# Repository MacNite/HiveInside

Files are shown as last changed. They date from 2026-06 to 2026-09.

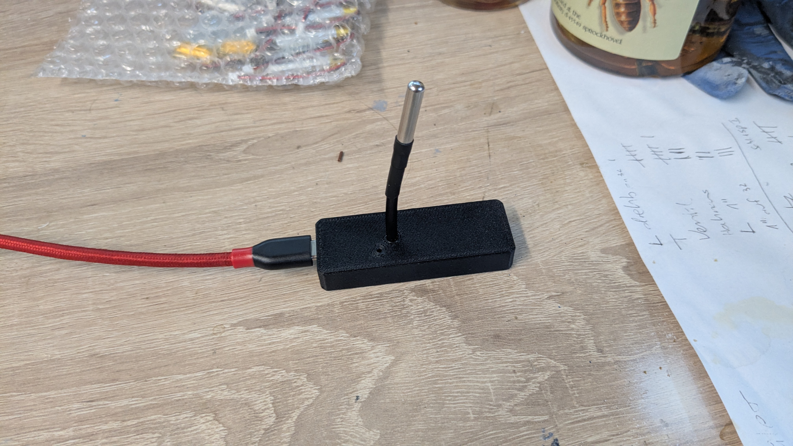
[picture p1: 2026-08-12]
enclosure/enclosure.jpg

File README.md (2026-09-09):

# HiveInside

A stand-alone, battery-powered **in-hive environmental and acoustic sensor** for
beehive monitoring. It broadcasts its readings over **BLE as a beacon** that the
[HiveScale](https://github.com/MacNite/HiveScale) / HiveHub ecosystem picks up
with a passive scan each cycle and bridges to the backend.

- **Target:** Seeed **XIAO nRF54LM20A Sense** with an external SHT40, for low power and a
  compact integrated sensor platform — its on-board 6-axis IMU (LSM6DS3TR-C),
  PDM mic (MSM261DGT006) and nPM1300 PMIC fold most of the discrete sensors onto
  the module. The firmware is a Zephyr application in
  [`firmware-nrf54lm20a/`](firmware-nrf54lm20a), built with west and sysbuild.
  [[buy]](https://www.seeedstudio.com/Seeed-Studio-XIAO-nRF54LM20A-Sense-p-6840.html)

> Part of the open beehive-monitoring ecosystem alongside **HiveScale** (weight /
> external sensing) and **BeeCounter** (entrance traffic).

📖 **[HiveInside website](https://macnite.github.io/HiveInside/website/)** — the
feature set, hardware and BLE payload on one page (source in
[`website/`](website)). The ecosystem hub is the
[HiveHub site](https://macnite.github.io/HiveHub/website/).

---

## Why a separate device?

The frame-mounted accelerometer is, per the literature (Ramsey et al. 2020,
*Sci. Rep.*), the only reliable way to **predict swarming** up to ~30 days ahead —
microphones cannot capture the critical ~20 Hz vibrational signature. HiveInside
puts that accelerometer, plus acoustic FFT bands and climate sensing, **inside**
the hive on a tiny wireless board, avoiding the cabling a wired sensor needs.

---

## Sensors

| Function | Part (XIAO nRF54LM20A Sense) | Interface |
|---|---|---|
| 3-axis vibration (swarm prediction, ~20 Hz) | LSM6DS3TR-C (on-board 6-axis IMU) | I²C |
| Acoustic FFT (piping, hum, stress) | MSM261DGT006 (on-board PDM mic) | PDM |
| Temperature + humidity | SHT40 (external) | I²C |
| Battery voltage + charge | nPM1300 PMIC fuel gauge (on-board) | — |

The firmware also auto-detects an external LIS3DH/LIS2DH12 at `0x18`/`0x19`, so a
breakout-based bench setup runs the same pipeline as the on-board IMU.

Vibration and acoustics are analysed into the same FFT bands as HiveScale, so a
value means the same thing across the ecosystem.

---

## Key features

- **BLE beacon transport** — the full measurement (climate, vibration +
  acoustic FFT bands, battery) broadcasts continuously as a 29-byte
  manufacturer-data advertisement that HiveHub decodes with a passive scan.
  Reading the data needs no connection, pairing window, or wake-sync schedule.
- **Per-node identity** — each node advertises as `HiveInside-XXXX`, where the
  four hex digits are the last two bytes of its BLE address. Several nodes in
  one yard are therefore distinguishable in a scanner and in HiveHub's dashboard
  without any provisioning step; the suffix is derived from the address, so it
  survives a factory erase and a firmware update.
- **Ultra-low power** — the nRF54 idles with only the ~1 s advertiser
  running (a few µA); no deep-sleep rendezvous machinery required. The sensor
  rail (IMU + microphone) is switched off between the five-minute measurements.
- **Authenticated on-request audio** (0.6.0+) — HiveHub can ask the node to
  record from inside the hive; it streams raw 16 kHz PCM16 over BLE with a
  60-second privacy cap, an HMAC-authenticated START and an end-to-end CRC. The
  microphone stays off until an authenticated request owns the link, and a
  session can never overlap a measurement cycle or an OTA.
  See [`docs/audio-over-ble.md`](docs/audio-over-ble.md).
- **Firmware-over-BLE (OTA)** — implemented: MCUboot dual-slot with a small
  GATT service that streams the signed image into the secondary slot, verifies
  size + CRC-32, and test-swaps with automatic rollback. The device therefore
  advertises *connectable* (`ADV_IND`); the measurement payload itself is still
  read passively from the advertisement.
  See [`docs/ota-over-ble.md`](docs/ota-over-ble.md).
- **Zephyr with sysbuild** — one toolchain for everything. `west --sysbuild`
  builds MCUboot and the signed application together, which is what makes a
  bootable image and an OTA payload; the repository ships a `west.yml` so the
  workspace is reproducible. **West with sysbuild is the only supported build
  path**; there is no parallel application tree or alternate build frontend.

---

## Repository layout

```
HiveInside/
├── west.yml              west manifest (pins the Zephyr revision to build against)
├── firmware-nrf54lm20a/  Zephyr application (XIAO nRF54LM20A Sense)
│   ├── prj.conf          Zephyr config + app.overlay (board DT tweaks)
│   ├── low-power.conf    deployment profile, layered on top (docs/low-power.md)
│   ├── sysbuild/         MCUboot child-image config for `west --sysbuild`
│   └── src/              main + sensor + FFT + beacon + OTA modules
├── enclosure/            Current 3D-printable enclosure files
├── tools/flash/          OpenOCD flashing scripts for the prebuilt release images
├── docs/                 wiring, building, flashing, OTA, Home Assistant
└── README.md
```

---

## Quick start (XIAO nRF54LM20A Sense)

**Just want a running node?** Every
[release](https://github.com/MacNite/HiveInside/releases) ships prebuilt images:
a `-factory.hex` you flash over USB with the bundled `flash.sh` / `flash.ps1`
(OpenOCD, no toolchain), and a `.signed.bin` you push to an existing node over
the air through HiveHub. Pick the `lowpower` variant for a hive and `bringup`
for the bench. See
[`docs/flashing.md`](docs/flashing.md#flashing-a-prebuilt-release-image).

To build it yourself, set up a west workspace from this repository, then build
and flash:

```bash
west init -m https://github.com/MacNite/HiveInside hiveinside-workspace
cd hiveinside-workspace && west update
west build --sysbuild -b xiao_nrf54lm20a/nrf54lm20a/cpuapp -d debug hiveinside/firmware-nrf54lm20a
west flash -d debug
picocom -b 115200 /dev/ttyACM0   # serial console over the on-board debugger
```

`--sysbuild` is not optional: the firmware boots through MCUboot, so a bootable
device needs the bootloader **and** the signed application, and only a sysbuild
build produces both (plus the OTA payload). A plain `west build` yields an
application-only image with nothing at `0x0`, which does not boot.

See [`docs/vscode-build.md`](docs/vscode-build.md) to build it from VS Code or
VSCodium, [`docs/flashing.md`](docs/flashing.md) for flashing details and
troubleshooting, and [`firmware-nrf54lm20a/README.md`](firmware-nrf54lm20a/README.md)
for the readout format, BLE frame layout, and roadmap.
For the authenticated on-request PCM protocol, see [`docs/audio-over-ble.md`](docs/audio-over-ble.md).
For battery deployment, see the audited [`low-power build profile`](docs/low-power.md),
including measurement guidance and upstream references.

---

## Status

🚧 **Bring-up in progress; not yet hardware-validated in the field.** The
firmware reads all four sensors (SHT40 climate, LSM6DS3TR-C acceleration, PDM
microphone level, nPM1300 battery), performs the vibration/acoustic FFTs, prints
the readout, and broadcasts the HiveHub-compatible BLE measurement beacon.
Active scans additionally receive its XIAO nRF54LM20A board identity and
firmware version without changing the measurement advertisement.
Firmware-over-BLE is implemented on top of MCUboot.
See [`firmware-nrf54lm20a/README.md`](firmware-nrf54lm20a/README.md) for the
readout format and roadmap, and [`docs/wiring.md`](docs/wiring.md) for the
XIAO and SHT40 connection reference.

## License

MIT — see [`LICENSE`](LICENSE).

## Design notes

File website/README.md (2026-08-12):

# HiveInside website

A small, dependency-free static site for HiveInside — a single page:

- **`index.html`** — the landing page: what the device is and why it exists
  (the ~20 Hz pre-swarm vibration a microphone cannot capture), the feature
  set, the hardware and wiring, what the BLE beacon actually contains
  (the FFT bands plus the 29-byte frame layout), a build-and-flash walkthrough,
  and where it sits in the ecosystem around
  [HiveHub](https://macnite.github.io/HiveHub/website/).
- **`assets/style.css`**, **`assets/theme.js`** — verbatim copies of the
  HiveHub website's shared stylesheet and dark-mode switcher
  (`website/assets/` in [MacNite/HiveHub](https://github.com/MacNite/HiveHub)),
  so both sites look and behave the same. Re-copy them to pick up changes;
  don't edit them here. Page-specific styles live in an inline `<style>` block
  in `index.html`, the same way HiveHub's `build.html` does it.

There is no build step — it is plain HTML/CSS/JS.

The dark-mode preference is stored under the **`hivehub-theme`** key on
purpose. Both sites are served from the `macnite.github.io` origin and so share
one `localStorage`; using the same key means a visitor who picks dark mode on
either site gets it on the other.

The page's content mirrors the repository documentation — the top-level
[`README.md`](../README.md),
[`firmware-nrf54lm20a/README.md`](../firmware-nrf54lm20a/README.md) (feature
set and BLE frame), [`docs/wiring.md`](../docs/wiring.md) (hardware) and
[`docs/low-power.md`](../docs/low-power.md) (battery). Update it when those
change; in particular the **status banner** at the bottom of the page says the
device is not yet hardware-validated in the field, and the battery numbers are
described as planning estimates rather than measurements. Both need revisiting
once real hardware figures exist.

## Preview locally

Open `website/index.html` in a browser, or serve the folder:

```bash
cd website
python3 -m http.server 8080
# then open http://localhost:8080/
```

## Publish on GitHub Pages

A workflow at [`.github/workflows/pages.yml`](../.github/workflows/pages.yml)
deploys this folder automatically. Enable it once:

1. Push these files to `main`.
2. In the repository, go to **Settings → Pages**.
3. Under **Build and deployment → Source**, choose **GitHub Actions**.

The workflow publishes the folder at **both** the Pages root and under
`/website/`, so the site answers at

- `https://macnite.github.io/HiveInside/` and
- `https://macnite.github.io/HiveInside/website/`.

That duplication is deliberate. Pages can only serve a branch from `/` or
`/docs`, never from `/website`, so the alternative "Deploy from a branch"
source would serve the repository as-is and put the site at
`…/HiveInside/website/` — a different URL from the one this workflow would
otherwise produce. Publishing both means external links (the HiveHub site
points here) survive either choice. The links **out** of this page are absolute
`https://` URLs, so they are unaffected either way.

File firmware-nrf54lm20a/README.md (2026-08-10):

# HiveInside — nRF54LM20A firmware

Firmware for the **Seeed XIAO nRF54LM20A Sense**, built with **Zephyr** —
`west --sysbuild`, from the command line or the nRF Connect VS Code extension.

The firmware reads every sensor, prints the readings to the USB serial console,
runs the **same vibration and acoustic FFT band analysis as HiveScale/HiveHub**,
and broadcasts each reduced result as a BLE beacon. The 29-byte
manufacturer-data frame keeps its 26-byte version-1 prefix directly compatible
with the current HiveHub passive scanner; reading the measurement needs no BLE
connection and no wake synchronisation.

## What it reads

Every `MEASURE_INTERVAL_MS` (default 5 min) the firmware reads all four sensors
and prints a block to the console:

| Group | Sensor | Source |
|---|---|---|
| Climate | SHT40 (external, XIAO I²C header, `0x44`) | raw I²C, low-precision measure |
| Vibration | LSM6DS3TR-C on-board IMU (I²C `0x6A`) | raw I²C, ~1024 samples @ ~400 Hz → mean X/Y/Z + FFT bands (mg) |
| Sound | MSM261DGT006 on-board PDM mic | Zephyr `dmic` API, RMS/peak + FFT bands (dBFS) |
| Battery | nPM1300 PMIC fuel gauge | Zephyr sensor API (`SENSOR_CHAN_GAUGE_VOLTAGE`) |

The accelerometer probe auto-detects the chip by `WHO_AM_I`, so an external
LIS3DH/LIS2DH12 breakout (`0x18`/`0x19`) also works for bench comparisons.

The FFT bands are the ecosystem-shared bands:

- **Vibration (mg, gravity removed):** swarm `8–30 Hz`, fanning `30–100 Hz`,
  activity `100–200 Hz`.
- **Acoustic (dBFS):** sub-bass `50–150 Hz`, hum `150–300 Hz`, piping
  `300–550 Hz`, stress `550–1500 Hz`, high `1500–3000 Hz`.

Each group prints `n/a` when its sensor is missing or the read failed that
cycle, so a partial board still gives a useful readout.

## BLE data transfer

The node sends one **legacy connectable undirected (`ADV_IND`)** advertisement
containing a 29-byte manufacturer-data value. The measurement itself is read
passively out of that advertisement — the connectable PDU type exists only so a
relay can open the firmware-over-BLE service (see
[`../docs/ota-over-ble.md`](../docs/ota-over-ble.md)); no GATT characteristic
carries sensor data.

Format version 2 retains every version-1 field at the same offset and appends
acceleration peak and microphone peak, so existing HiveHubs continue to decode
the core data while an updated decoder can expose both peaks. A sensor failure
clears that group's validity flag, preventing the server from interpreting
zero-filled bytes as a real measurement.

All multi-byte fields are little-endian. Offsets count from the start of the
manufacturer-specific data, i.e. including the two company-ID bytes:

| Offset | Field | Encoding | Valid when |
|---:|---|---|---|
| `0..1` | Company ID | `0x02E5` | always |
| `2` | Magic | `0x48` (`H`) | always |
| `3` | Format version | `2` | always |
| `4` | Validity flags | bit 0 climate, 1 accel, 2 mic, 3 battery | always |
| `5..6` | Temperature | `int16`, 0.1 °C/LSB | climate flag |
| `7..8` | Humidity | `uint16`, 0.1 %RH/LSB | climate flag |
| `9..10` | Battery voltage | `uint16`, 1 mV/LSB | battery flag |
| `11` | Battery charge | `uint8`, % (0–100) | battery flag |
| `12..13` | Acceleration RMS | `uint16`, 0.1 mg/LSB | accel flag |
| `14..15` | Vibration band — swarm (8–30 Hz) | `uint16`, 0.1 mg/LSB | accel flag |
| `16..17` | Vibration band — fanning (30–100 Hz) | `uint16`, 0.1 mg/LSB | accel flag |
| `18..19` | Vibration band — activity (100–200 Hz) | `uint16`, 0.1 mg/LSB | accel flag |
| `20` | Microphone RMS | `int8`, 1 dBFS/LSB | mic flag |
| `21` | Acoustic band — sub-bass (50–150 Hz) | `int8`, 1 dBFS/LSB | mic flag |
| `22` | Acoustic band — hum (150–300 Hz) | `int8`, 1 dBFS/LSB | mic flag |
| `23` | Acoustic band — piping (300–550 Hz) | `int8`, 1 dBFS/LSB | mic flag |
| `24` | Acoustic band — stress (550–1500 Hz) | `int8`, 1 dBFS/LSB | mic flag |
| `25` | Acoustic band — high (1500–3000 Hz) | `int8`, 1 dBFS/LSB | mic flag |
| `26..27` | Acceleration peak *(v2)* | `uint16`, 0.1 mg/LSB | accel flag |
| `28` | Microphone peak *(v2)* | `int8`, 1 dBFS/LSB | mic flag |

HiveHub decoders that only understand the 26-byte version-1 prefix safely
ignore the two trailing v2 fields. They continue to ingest every existing field,
but must add the offsets above before the two new peaks appear in backend data.

The primary advertisement is exactly full: 29 data bytes plus the AD length and
type byte fill the 31-byte legacy limit. The optional **BLE Flags** AD element is
therefore omitted, which is what makes the three peak-extension bytes fit without
extended advertising. One consequence is worth knowing: without a Flags element
the device is formally *non-discoverable*, so scanners that filter on the
general/limited discoverable bits may not list it even though it is connectable.
HiveHub's passive scan and a direct connect by address are unaffected.

The human-readable device name `HiveInside` rides in the scan response instead.
This preserves the complete manufacturer payload for HiveHub's passive scanner
while letting an active setup scan display a friendly name. The source also
declares the manufacturer name as `HiveInside`; on the BLE wire,
manufacturer-specific data contains only the numeric company ID (`0x02E5`), as
required by the BLE AD format.

Active scans also receive a compact manufacturer-data identity record in the
scan response. It does not alter the full 29-byte measurement advertisement or
the USB console path.

| Offset | Field | Value |
|---:|---|---|
| `0..1` | Company ID | `0x02E5`, little-endian |
| `2` | Record magic | `0x49` (`I`) |
| `3` | Record version | `1` |
| `4` | Board ID | `2` (Seeed XIAO nRF54LM20A) |
| `5..7` | Firmware version | major, minor, patch bytes |

The Bluetooth controller repeats the latest measurement every second. HiveHub
therefore receives it during its existing shared passive scan and forwards it
with the next server upload. Pair the node by its stable identity address as
**HiveInside (nRF54LM20A) — beacon**.

### Watchdog

A sealed node has no console and nobody watching it, so a hang inside a sensor
driver — a stuck I²C transfer, a `dmic_read()` that never returns — would leave
the firmware alive enough to keep advertising the last good measurement
indefinitely. From HiveHub that looks like a hive that simply stopped changing.

`src/watchdog.c` arms `wdt31` with a 60 s timeout and `main.c` feeds it, both at
the top of each cycle and every 20 s through the long idle between cycles, so
the timeout is sized against one stuck driver call rather than against
`MEASURE_INTERVAL_MS`. The OTA polling loop feeds it too: a firmware upload
legitimately takes minutes and must not be cut short. Adjust with
`HIVE_WDT_TIMEOUT_MS` / `HIVE_WDT_FEED_INTERVAL_MS` in `hive_config.h`.

The watchdog is recovery, not reporting. It resets a wedged node; it cannot
tell you that it happened. A node whose readings jump back to boot defaults is
the symptom to look for.

### Radio sleep and battery life

For the full code/hardware audit, production build profile, measurement method,
and upstream references, see [`../docs/low-power.md`](../docs/low-power.md).

- The firmware switches nPM1300 LDO1 off after each acquisition and restores it
  shortly before the next one. This removes the on-board IMU and microphone's
  standby load for nearly all of the five-minute measurement interval. The PMIC
  and external SHT40 remain available because they use other supplies.
  With the default settings the rail is needed for roughly 3.2 s per 300 s
  cycle (about 1.1% duty cycle). Using typical component standby figures as a
  planning estimate, switching it off saves approximately **10–20 uA average**
  at the battery, or **0.24–0.48 mAh/day** (**88–175 mAh/year**). This is not a
  whole-device battery-life prediction: BLE, the SoC, PMIC, SHT40, battery
  self-discharge, temperature, and regulator losses remain. Confirm the result
  on production hardware with a power analyzer, because board leakage and
  component spread can be comparable to these small standby currents.
- Keep advertising continuous. The nRF controller autonomously sleeps between
  the three short advertising-channel transmissions, and the application CPU
  remains asleep. Stopping BLE between measurements would save a little radio
  energy but makes a short, unsynchronised HiveHub scan likely to miss the node.
- The default one-second interval is the reliability/power compromise expected
  by HiveHub. `BLE_ADV_INTERVAL_MS` can be overridden at build time; increase it
  only after making sure the HiveHub scan window is several times longer than
  the chosen interval. Avoid intervals longer than the scan window.
- Sensor acquisition—especially the multi-second accelerometer capture and PDM
  microphone—is expected to dominate energy use, not beacon advertising. The
  five-minute field default produces two fresh samples per ten-minute reporting
  period. Set it to ten minutes for longer battery life if one fresh sample per
  reporting period is sufficient. Scan-window overlap is not a reason to sample
  more often: the last valid result continues advertising while the CPU sleeps.
- Do not use system-off/deep sleep for the normal cycle: it stops the BLE
  controller and defeats asynchronous passive scanning. Zephyr `k_msleep()`
  already lets the kernel and radio enter their supported idle states. Reserve
  system-off for storage/shipping mode, where discoverability is intentionally
  disabled.

Example output:

```
[HiveInside] nrf54lm20a fw 0.4.5 | USB + HiveHub BLE beacon
[PWR] nPM1300 LDO1 at 3.3V (IMU + mic rail)
[BLE] ready; name=HiveInside manufacturer=HiveInside id=0x02e5 interval=1000 ms
[SHT40] present on i2c@...
[ACCEL] LSM6DS3TR-C at 0x6A on i2c@...
---- HiveInside readout ----
  climate : 24.31 C   47.8 %RH
  accel   : x=-3.2 y=1.8 z=1004.6 mg  |a|=1004.6 mg
  accel AC: rms=2.4 peak=9.1 mg  (1024@416Hz)
  vib FFT : swarm=0.42 fan=0.18 act=0.09 mg
  sound   : rms=-61.4 dBFS  peak=-42.1 dBFS  (8000 frames)
  ac FFT  : sub=-58.2 hum=-49.7 pipe=-63.1 stress=-71.4 hi=-88.0 dBFS
  battery : 4.011 V  ~78%
----------------------------
[BLE] measurement advertised (flags=0x0f)
```

After each successful measurement advertisement update, the built-in blue LED
lights for `MEASUREMENT_LED_BLINK_MS` (default 100 ms). It does not blink for the
controller's automatic one-second repeats, only when fresh sensor data is
published.

## Build, flash, monitor

This firmware boots **through MCUboot** so it can accept firmware-over-BLE
updates (see [`../docs/ota-over-ble.md`](../docs/ota-over-ble.md)). A bootable
image is therefore MCUboot **plus** a signed application in slot 0, produced as
two flash domains by a `west --sysbuild` build. `west flash` programs both; an
nRF Connect SDK workspace may additionally emit a convenience `merged.hex`. A
build without `--sysbuild` covers the **application alone**, so it is a compile
check and never a bootable image.

```bash
# One-time: a west workspace at the Zephyr revision pinned in ../west.yml.
west init -m https://github.com/MacNite/HiveInside hiveinside-workspace
cd hiveinside-workspace && west update

# Build + flash the real, bootable OTA image (MCUboot + signed app):
west build --sysbuild -b <board-target> -d debug hiveinside/firmware-nrf54lm20a
west flash -d debug   # programs MCUboot + the signed app over the on-board debugger
                      # (run it against the TOP-LEVEL sysbuild build directory)

picocom -b 115200 /dev/ttyACM0   # serial console (see below)
```

Building from VS Code / VSCodium with the nRF Connect extension — the `debug`
configuration and the `lowpower` one for the deployment image — is documented in
[`../docs/vscode-build.md`](../docs/vscode-build.md).

Each `west` build also writes a version-stamped copy of the signed application
next to `zephyr.signed.bin`, so a release artifact still identifies itself once
it is detached from its build directory:

```
<build>/firmware-nrf54lm20a/zephyr/hiveinside-nrf54lm20a-v0.4.5-bringup.signed.bin
```

The version comes from `HIVEINSIDE_FW_VERSION_MAJOR`/`_MINOR`/`_PATCH` in
`src/hive_config.h` — the same numbers the node advertises; the
`-bringup` / `-lowpower` suffix is derived from `CONFIG_SERIAL` in the image
actually built, so a deployment image built with the
[`low-power`](../docs/low-power.md) profile can never be mistaken for a
console-enabled one when picking an OTA payload. Upload that file rather than
`zephyr.signed.bin` — see [`../docs/ota-over-ble.md`](../docs/ota-over-ble.md).

> ⚠️ **Never flash a build made without `--sysbuild`.** With MCUboot enabled the
> application links at the slot-0 offset, so flashing it alone leaves nothing at
> `0x0`: the CPU faults before `main()` runs and the device goes silent (no
> serial, no BLE). Build with `--sysbuild` and flash the merged image with
> `west flash`.

The XIAO nRF54LM20A Sense has an **on-board SAMD11 CMSIS-DAP debugger** (VID:PID
`0x2886:0x0068`) on the USB-C connector, so no external probe is needed — both
`west flash` and the serial console ride the same USB-C cable through it.

### Serial console over the same USB cable

The SAMD11 also exposes a **USB CDC ACM port** bridged to the SoC's `uart20`, so
`printk()` output appears on the host over the same USB-C cable used for
flashing. It runs at **115200 8N1** and enumerates on Linux as `/dev/ttyACM0`
and on macOS as `/dev/cu.usbmodem*` (run `ls /dev/cu.usbmodem*` to get the exact
name — there is no `/dev/ttyACM0` on macOS).

```bash
picocom -b 115200 /dev/ttyACM0            # Linux (or: screen /dev/ttyACM0 115200)
picocom -b 115200 /dev/cu.usbmodemXXXX    # macOS
```

The boot banner prints once at reset; press **RST** with the monitor connected
to see it and the first readout. The console is a plain polled UART, so the
firmware runs whether or not a terminal is attached.

An unconnected sensor never silences the console — the banner comes before any
sensor access and a missing SHT40 just prints `climate : n/a`. If there is no
output *and* no BLE advertising, the application is not running at all; see
"Device is silent after flashing" in [`../docs/flashing.md`](../docs/flashing.md).

### Microphone bring-up

The on-board microphone needs all three pieces of the Sense-board setup: P1.12
must enable the sensor power gate, nPM1300 LDO1 must supply 3.3 V, and `pwm20`
must be disabled because it shares a peripheral instance with `pdm20`. The
overlay configures the latter two, while `power_init()` explicitly enables the
power gate and LDO1 before the first capture. Microphone errors include the
Zephyr return code on the serial console, which makes a wiring/driver failure
distinguishable from silence.

See [`../docs/flashing.md`](../docs/flashing.md) for the external-probe
alternative and the `west` workflow, and [`../docs/wiring.md`](../docs/wiring.md)
for the SHT40 and battery connections.

## Layout

```
firmware-nrf54lm20a/
├── sysbuild.conf         enable MCUboot for the west --sysbuild build
├── sysbuild/mcuboot.conf MCUboot child-image config (small, console off, board
│                         power-management drivers off — see the file's comments)
├── CMakeLists.txt        application entry point (source list)
├── prj.conf              Zephyr config   ┐ both picked up automatically by
├── app.overlay           board DT tweaks ┘ Zephyr; no build field points at them
├── *_fixups.overlay      SDK-specific DT fixups selected by CMakeLists.txt
├── low-power.conf        opt-in deployment profile ─┐ see docs/low-power.md
├── low-power.overlay     opt-in deployment DT tweaks┘
├── cmake/
│   └── stamp_ota_payload.cmake  version-stamped copy of zephyr.signed.bin
└── src/
    ├── main.c            sensor loop + console print + beacon publish
    ├── beacon.[ch]       HiveHub-compatible manufacturer-data advertising
    ├── ota.[ch]          firmware-over-BLE GATT service → MCUboot slot 1
    ├── hive_config.h     addresses, timing, bands, per-sensor settings
    ├── measurement.h     one sensor snapshot, shared by every module
    ├── hive_i2c.[ch]     enumerate every enabled I²C bus for probing
    ├── fft.[ch]          dependency-free radix-2 FFT + band reduction
    ├── power.[ch]        nPM1300 LDO1 → 3.3 V sensor rail
    ├── watchdog.[ch]     wdt31 hardware watchdog, fed from the main loop
    ├── sht40.[ch]        SHT40 climate
    ├── accel.[ch]        LSM6DS3TR-C / LIS3DH vibration + FFT bands
    ├── mic.[ch]          PDM microphone level + FFT bands
    └── battery.[ch]      nPM1300 fuel gauge
```

> **One copy of every config file.** `prj.conf` and `app.overlay` live only in
> this application directory, where Zephyr discovers them automatically. Do not
> create a second application root or duplicate either file: west with sysbuild
> is the only supported build path.

## Roadmap

1. **Sensor readout over USB** — done.
2. **Vibration + acoustic FFT band analysis** (the bands shared with
   HiveScale/HiveHub) — done, printed to the console alongside the raw readings.
3. **BLE measurement beacon** (the 29-byte manufacturer-data advertisement
   HiveHub ingests) — done.
4. **BLE board/firmware identity** (compact scan-response record) — done.
5. **Firmware-over-BLE (MCUboot/DFU)** — implemented (GATT OTA service +
   streaming into slot 1 + MCUboot test-swap). Requires a `west --sysbuild`
   build/flash of the merged image; an application-only build cannot boot.

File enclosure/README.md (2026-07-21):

# Enclosure

This folder contains the most recent 3D-printed enclosure design for the Seeed
XIAO nRF54LM20A Sense, SHT40, and a 500 mAh LiPo battery.

Store the current release files here in these formats:

- STL (`.stl`)
- 3MF (`.3mf`)
- Fusion 360 (`.f3d`)
- STEP (`.stp`)

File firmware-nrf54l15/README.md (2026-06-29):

# HiveInside — XIAO nRF54L15 Sense firmware (nRF Connect SDK / Zephyr)

The next-generation HiveInside node, moving from the XIAO ESP32-C6 prototype
(`firmware-esp32-c6/`) to the **Seeed XIAO nRF54L15 Sense** for much lower
power and a single integrated board (on-board IMU + PDM mic).

- **MCU:** nRF54L15 — Cortex-M33 @ 128 MHz, FPU + DSP, 1.5 MB RRAM, 256 KB RAM,
  Bluetooth LE 6.0. Plus a RISC-V (FLPR) coprocessor we can ignore for now.
- **On-board IMU:** ST **LSM6DS3TR-C** (6-axis) — used for the swarm-band
  vibration FFT (the ~8–30 Hz pre-swarm signal from Ramsey et al. 2020).
- **On-board mic:** **MSM261DGT006** PDM MEMS microphone — acoustic FFT.
  The nRF54L15 has a **hardware PDM peripheral** that decodes PDM → PCM in
  hardware, so we drop the software sinc decimator the ESP32-C6 needed.
- **Later:** external **SHT40** (temp/humidity) over I²C.

## Why nRF Connect SDK (and yes, it's an RTOS)

nRF Connect SDK (NCS) **is** Zephyr RTOS + Nordic's BLE stack and drivers —
there is no supported bare-metal path for the nRF54L family, and you don't want
one. For a low-power beacon the RTOS *helps*:

- The kernel is **tickless** and the idle thread automatically drops the SoC
  into low-power modes whenever no thread is runnable. Between measurements the
  chip sits in System ON idle with RAM retention at single-digit µA — without
  you hand-rolling sleep logic like the ESP32-C6 `enterDeepSleep()`.
- Battery, you don't fight it: a beacon can live almost entirely in `main()`
  plus a `k_timer`, so the RTOS stays out of the way while still giving you the
  Nordic BLE controller, the PDM/DMIC driver, the LSM6DS3TR-C sensor driver and
  CMSIS-DSP for the FFT — all as drop-in modules.

So: **use NCS (Zephyr). Don't disable the RTOS.** Low power comes from short
wake windows and the built-in idle, not from going bare-metal.

---

## Step 0 — Install the toolchain + SDK (one time)

You said the Nordic VS Code plugins are already installed. Finish the setup:

1. Open **nRF Connect for VS Code** → the **nRF Connect** sidebar icon.
2. **Install Toolchain** — pick the version that matches the SDK below (the
   extension pairs them). This is the compiler + `west` + native tools.
3. **Install SDK** — install a recent **nRF Connect SDK** release that has
   nRF54L15 production support and that the Seeed board files target (the
   current Seeed `platform-seeedboards` samples track the recent NCS line; pick
   the newest offered unless their wiki pins an exact version).
4. **Add the Seeed board files** (the XIAO nRF54L15 board isn't in your SDK tree
   until you point Zephyr at Seeed's definitions):
   ```bash
   git clone https://github.com/Seeed-Studio/platform-seeedboards.git
   ```
   Then in VS Code: **Settings → search "nRF Connect: Board Roots" → Edit in
   settings.json** and add the path to `platform-seeedboards/zephyr` to the
   `boardRoots` array. Reload the window.
   *(Check the Seeed wiki "Getting Started" page for the exact current path —
   board file layouts move between SDK versions.)*

## Step 1 — Blinky (this folder)

Confirms the toolchain, board target and flashing path before any sensors.

**Build (VS Code):** nRF Connect sidebar → **Add build configuration** → select
board target **`xiao_nrf54l15/nrf54l15/cpuapp`** → **Build Configuration**.

**Build (CLI):**
```bash
west build -b xiao_nrf54l15/nrf54l15/cpuapp firmware-nrf54l15
```

**Flash:** the XIAO has no on-board debugger, so either:
- **UF2 bootloader (no extra hardware):** double-tap **RESET** to mount the
  board as a USB drive, then drag `build/zephyr/zephyr.uf2` onto it; **or**
- **SWD debugger** (J-Link / other) on the XIAO's SWD pads → VS Code **Flash**
  button, or `west flash`.

> Confirm the flashing method on the Seeed wiki for your board revision before
> relying on it — some XIAO revisions ship with the UF2 bootloader, some expect
> an external debugger.

✅ **Success = the on-board user LED blinks at 1 Hz** and `HiveInside nRF54L15
blinky up …` prints on the serial console (115200 baud over the USB CDC-ACM).

---

## Roadmap to the real firmware (after blinky works)

Planned build order — each step is independently testable on the bench:

1. **BLE beacon shell.** Non-connectable **extended advertising** with a
   manufacturer-data payload (dummy values first). Verify in the nRF Connect
   mobile app. This is the low-power transport: no connection, radio on only for
   a short advertising burst each cycle.
2. **IMU (LSM6DS3TR-C).** Enable the Zephyr sensor driver from the Seeed
   devicetree node; capture a fixed buffer at a known ODR (~400 Hz) for the FFT.
3. **Mic (PDM/DMIC).** Use the Zephyr DMIC API on the nRF PDM peripheral —
   hardware PDM→PCM, 16 kHz. Short capture window (~100–250 ms) to keep power
   down; the mic is the biggest consumer.
4. **DSP features (CMSIS-DSP).** `arm_rfft_fast_f32` on the M33 for both
   domains. Compute the **same band energies as HiveScale** so values mean the
   same thing across the ecosystem (acc: swarm 8–30 / fanning 30–100 /
   activity 100–200 Hz; sound: sub-bass / hum / piping / stress / high — see
   `firmware-esp32-c6/include/config.h`).
5. **Pack + broadcast.** RMS sound, RMS acc, the FFT **band energies + peak
   bin** per domain, temp, humidity, battery — see payload note below.
6. **Power management.** `k_timer` wake cadence, short adv burst, idle between;
   tune the interval. Measure with a Power Profiler Kit if available.
7. **SHT40** over I²C (external, added last as you noted).
8. **Battery voltage** via SAADC — *needs schematic confirmation* of whether the
   XIAO nRF54L15 Sense exposes a BAT+ divider net and an enable GPIO.

### ⚠️ Important design note: you can't beacon a *full* FFT

A legacy BLE advert is 31 bytes total; even BLE 5 **extended advertising** tops
out around 254 bytes. A full spectrum (hundreds of bins) neither fits nor is
worth the airtime/power. So the beacon carries **features, not raw FFT**:

- RMS sound, RMS acc (≈2 bytes each)
- per-band energies — the HiveScale bands above (≈1–2 bytes/band)
- peak frequency + magnitude per domain
- temp, humidity, battery

That's ~30–40 bytes — comfortable in one extended advert. The on-device FFT
still runs at full resolution; we just transmit the distilled result. If you
ever need the *raw* spectrum off the device, that's the point to add an optional
**connectable GATT** characteristic (like the ESP32-C6 build), accepting the
extra power cost of a connection — but the default stays pure beacon.

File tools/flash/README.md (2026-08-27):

# HiveInside flashing tools

Flash a **prebuilt** HiveInside image onto a Seeed XIAO nRF54LM20A Sense with
nothing but OpenOCD and a USB-C cable — no Zephyr toolchain, no west workspace,
no external probe. The board's on-board SAMD11 CMSIS-DAP debugger does the work.

These scripts also ship as `hiveinside-flash-tools.zip` on every
[release](https://github.com/MacNite/HiveInside/releases), together with the
board's OpenOCD config taken from the exact Zephyr revision the images were
built against.

If you already have a west workspace, keep using `west flash` — see
[`docs/flashing.md`](../../docs/flashing.md). This is for everyone else.

## Which file do I flash?

Each release carries two images per variant. They are not interchangeable:

| File | Use it for | How |
| --- | --- | --- |
| `hiveinside-nrf54lm20a-v<version>-<variant>-factory.hex` | A **new or bricked board**, over USB | the scripts here |
| `hiveinside-nrf54lm20a-v<version>-<variant>.signed.bin` | **Updating a running node**, over the air | upload it in HiveHub |

> ⚠️ Never flash the `.signed.bin` over SWD. It is the application alone, so it
> leaves nothing at `0x0`: the CPU faults before `main()` and the device goes
> completely silent — no console, no BLE. The scripts refuse it for you.

And pick the right **variant**:

* **`lowpower`** — the deployment profile. No console, no LED, minimum idle
  current. This is what goes into a hive.
* **`bringup`** — console on at 115200 8N1. Use it on the bench, while wiring up
  an SHT40 or watching the readout.

Both advertise identically, so a `bringup` image in a sealed hive looks fine
from HiveHub and simply drains the battery. Check the suffix before you flash.

## Prerequisites

OpenOCD 0.12 or newer:

```bash
sudo apt install openocd      # Debian/Ubuntu
brew install open-ocd         # macOS
sudo pacman -S openocd        # Arch
winget install OpenOCD.OpenOCD   # Windows (or the xPack OpenOCD build)
```

On Linux, allow non-root access to the debugger (Seeed VID `2886`):

```bash
echo 'SUBSYSTEM=="usb", ATTRS{idVendor}=="2886", MODE="0666"' \
  | sudo tee /etc/udev/rules.d/99-seeed-cmsis-dap.rules
sudo udevadm control --reload-rules && sudo udevadm trigger
```

Replug the board afterwards.

## Flashing

Unzip the release bundle, put the factory hex next to the scripts (or pass its
path), and run:

```bash
./flash.sh                                     # picks the single factory hex it finds
./flash.sh hiveinside-nrf54lm20a-v0.5.0-lowpower-factory.hex
```

```powershell
.\flash.ps1
.\flash.ps1 -Image hiveinside-nrf54lm20a-v0.5.0-lowpower-factory.hex
```

Both take `--openocd-cfg` / `-OpenocdCfg`, `--openocd` / `-Openocd` and
`--no-verify` / `-NoVerify`; `--help` prints the details.

The scripts run the same OpenOCD sequence `west flash --verify` runs for this
board, and verify the image by reading it back. **Leave the verification on** —
see below.

## Why the scripts patch the board config

The board's OpenOCD flash loader upstream is:

```tcl
proc nrf54lm20a-load {file} {
    mww 0x5004e500 0x101
    load_image $file
}
```

`0x5004e500` is `RRAMC.CONFIG`; `0x101` sets `WEN=1` **and a one-line (16-byte)
write buffer**, and the proc never commits that buffer. The nRF54L RRAM
controller only writes a 128-bit line out once the line fills, so any tail that
does not reach a 16-byte boundary stays in the buffer and never lands in RRAM.
On a signed image that truncates the signature TLV, and MCUboot then reports
`E: Image in the primary slot is not valid!` — with a silent, dark device to
show for it, because the bootloader console is disabled for size.

The scripts copy the config to a temp file and write `0x1` instead: same
register, write buffer off, every write commits. Flashing is slower, and
correct. Nothing on your disk is modified, and if a future Zephyr fixes the
loader upstream the scripts detect that and use the config unchanged.

This is upstream board support, not a HiveInside bug, and it affects any image
whose length is not a multiple of 16 bytes.

## Verifying what you downloaded

```bash
sha256sum -c SHA256SUMS      # shasum -a 256 -c SHA256SUMS on macOS
```

`manifest.txt` in the same release lists each OTA payload's byte size and
CRC-32 — the two values the OTA `BEGIN` frame carries — plus the Zephyr
revision and the commit the images were built from.

**On authenticity:** release images are signed with MCUboot's **development**
key, which is public. That gives image formatting, not proof of origin: a
device running these images will accept any image signed with the same public
key. Check the SHA-256 above to know you got the file we built.

## When it does not work

`docs/flashing.md` in the repository has the full troubleshooting path —
a silent device after flashing, `E: Image in the primary slot is not valid!`,
serial-port names per OS, and using an external probe. Start there.

## Contents of the release bundle

```
flash.sh, flash.ps1              these scripts
README.md                        this file
openocd/xiao_nrf54lm20a.cfg      the board's OpenOCD config, unmodified,
                                 from zephyrproject-rtos/zephyr (Apache-2.0)
openocd/ZEPHYR_REVISION          the Zephyr commit it was taken from — the same
                                 revision the images in the release were built
                                 against
```

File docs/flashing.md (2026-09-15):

# Flashing HiveInside

There are two ways to get firmware onto a board:

* **Flash a prebuilt release image** — a download and one command, no Zephyr
  toolchain. Start below.
* **Build it yourself** with `west --sysbuild` — the reference path, and the one
  to use when you are changing the firmware. That is the rest of this document,
  starting at [Target: XIAO nRF54LM20A Sense](#target-xiao-nrf54lm20a-sense).

---

## Flashing a prebuilt release image

Every [release](https://github.com/MacNite/HiveInside/releases) carries the
images CI built, in two variants, plus the tools to put them on a board.

### Pick the right file

| File | What it is | Flash it with |
| --- | --- | --- |
| `hiveinside-nrf54lm20a-v<version>-<variant>-factory.hex` | MCUboot at `0x0` **plus** the signed application in slot 0 — a complete, bootable device image | SWD over USB (below) |
| `hiveinside-nrf54lm20a-v<version>-<variant>.signed.bin` | The signed application alone: the **BLE OTA payload** | HiveHub, over the air |

`<variant>` is either **`lowpower`** — the deployment profile of
[`low-power.md`](low-power.md), no console, for a hive — or **`bringup`**, with
the console on at 115200 8N1 for bench work. Both advertise identically, so a
`bringup` image in a sealed hive looks healthy from HiveHub and just drains the
battery. Check the suffix before flashing.

`<version>` is the firmware version from `src/hive_config.h` — the same numbers
the node advertises — and is independent of the repository's release tag.

> ⚠️ **Never flash a `.signed.bin` over SWD.** It links at the slot-0 offset
> behind an MCUboot header, so on its own it leaves nothing at `0x0`: the CPU
> faults before `main()` and the device is completely silent. Use the
> `-factory.hex` for SWD and the `.signed.bin` only for OTA.

### Over USB, with the flashing bundle

Download `hiveinside-flash-tools.zip` and the factory hex for your variant from
the same release, unzip, and run:

```bash
./flash.sh hiveinside-nrf54lm20a-v0.5.0-lowpower-factory.hex
```

```powershell
.\flash.ps1 -Image hiveinside-nrf54lm20a-v0.5.0-lowpower-factory.hex
```

It needs OpenOCD on `PATH` and nothing else; the bundle carries the board's
OpenOCD config from the Zephyr revision the images were built against. On Linux
add the udev rule from the bundle's README so the debugger is usable without
`sudo`. The scripts run the same OpenOCD sequence `west flash --verify` runs,
verify the image by reading it back, and — importantly — correct the board's
RRAM loader first (see
[the OpenOCD RRAM bug](#known-bug-the-openocd-rram-loader-drops-the-last-partial-write);
the bundle's README explains the one-line fix).

The equivalent by hand, if you would rather not run a script, is:

```bash
openocd -f <board-openocd.cfg-with-the-RRAM-fix> \
  -c init -c "targets nrf54lm20a.cpu" -c "reset init" \
  -c "nrf54lm20a-load <image>.hex" \
  -c "reset init" -c "verify_image <image>.hex" \
  -c "reset run" -c shutdown
```

### Over the air, for a node that already runs

Upload the `.signed.bin` in HiveHub's firmware form. It reads the target and
version straight out of the file name, streams the image into the node's
secondary slot, and MCUboot test-swaps with automatic rollback. Nothing is
committed until size and CRC-32 verify, so a failed transfer leaves the node on
its old firmware. See [`ota-over-ble.md`](ota-over-ble.md).

### Check what you downloaded

```bash
sha256sum -c SHA256SUMS      # shasum -a 256 -c SHA256SUMS on macOS
```

`manifest.txt` in the release lists each payload's size and CRC-32 (the values
the OTA `BEGIN` frame carries), the commit and the Zephyr revision behind the
build, and `west-manifest-frozen.yml` plus `build-info-<variant>.zip` are there
to reproduce it.

The release workflow requires a project-owned MCUboot signing key and refuses to
produce these artifacts when its `HIVEINSIDE_SIGNING_KEY_PEM` secret is absent.
This is a required deployment step: the SDK's default development key is public,
so a node built with it accepts firmware from anyone using that known key. For a
local deployment build, generate and select the key with
`SB_CONFIG_BOOT_SIGNATURE_KEY_FILE` exactly as shown in the
[`ota-over-ble.md` production checklist](ota-over-ble.md#production-release-and-recovery-checklist).
Keep the private key outside the repository and preserve the matching public key
plus an SWD recovery path. Signing is currently the trust boundary because the
unencrypted OTA GATT writes have no HMAC; the filter-accept-list TODO remains in
`ota_init()` pending coordinated HiveHub bonding support.

### If the board does not come up

The troubleshooting further down this document applies unchanged — start at
[Device is silent after flashing](#device-is-silent-after-flashing-no-console-no-ble).

---

## Target: XIAO nRF54LM20A Sense

This firmware boots **through MCUboot** so it can accept firmware-over-BLE
updates (see [`ota-over-ble.md`](ota-over-ble.md)). A bootable image is therefore
MCUboot **plus** a signed application in slot 0. Only a **`west --sysbuild`**
build produces both, and both must reach the chip:

```bash
# From a west workspace carrying the XIAO nRF54LM20A board definition. The
# repository's own west.yml pins an upstream Zephyr revision that has it; an
# nRF Connect SDK workspace needs the board added out of tree (see below).
west build --sysbuild -b <board-target> -d debug path/to/firmware-nrf54lm20a
west flash -d debug           # programs every sysbuild image over the on-board debugger
picocom -b 115200 /dev/ttyACM0  # serial console over the same cable (see below)
```

`west flash` run against the **top-level** sysbuild build directory reads
`build/domains.yaml` and programs every image in flash order — MCUboot at `0x0`
and the *signed* application at slot 0 (`zephyr.signed.hex`; Zephyr's
`cmake/mcuboot.cmake` repoints the runner at it). Flashing a single image, or
flashing `build/firmware-nrf54lm20a/zephyr/zephyr.hex` by hand, leaves the
device unbootable — see "Device is silent after flashing" below.

> **`merged.hex` is an nRF Connect SDK artifact, not an upstream Zephyr one.**
> NCS's sysbuild concatenates the images into `build/merged.hex`; a plain
> `zephyrproject` workspace does **not** create that file, and it is not needed —
> `west flash` handles the multi-image case on its own. Where this document and
> [`ota-over-ble.md`](ota-over-ble.md) refer to `merged.hex` as the SWD
> factory/recovery image, that applies to NCS builds; on upstream Zephyr the
> equivalent is "everything `west flash` programs".

Use a pristine build when changing the board, partition layout, bootloader, or
signing configuration (`west build --pristine --sysbuild ...`). Before treating
the result as a release, inspect the generated partition report and retain the
artifacts for their distinct purposes: the full-flash image is for SWD
factory/recovery, while the application's `zephyr.signed.bin` is the BLE OTA
payload. Never send a full-flash image or the unsigned `zephyr.bin` through the
OTA characteristic.
See the production-key, release-test, and recovery checklist in
[`ota-over-ble.md`](ota-over-ble.md#production-release-and-recovery-checklist).

The board target is the west name of the Seeed board definition with its
nRF54L core qualifier (for example `xiao_nrf54lm20a/nrf54lm20a/cpuapp`); use the
exact name the board's `board.yml` declares.

The XIAO nRF54LM20A Sense has an **on-board SAMD11 CMSIS-DAP debugger** (Seeed
USB VID:PID `0x2886:0x0068`) connected to the SoC's SWD lines and brought out on
the USB-C connector. **No external probe is required** — plug the board into USB
and `west flash` programs the merged image over SWD through the on-board
debugger.

### A build without `--sysbuild` is not a flashing path

A plain `west build` produces a **single application image**. It never builds
MCUboot, signs the app, or emits a merged hex (`sysbuild.conf` and
`sysbuild/mcuboot.conf` are only read by a sysbuild build). It is useful as a
compile check and nothing more.

> ⚠️ **Do not flash an image built without `--sysbuild`.** With MCUboot enabled,
> the application links at the slot-0 offset (behind an MCUboot header), so
> flashing it alone leaves **nothing at `0x0`**: the CPU faults before `main()`
> runs and the device goes completely silent — no serial output, no BLE. This is
> the classic "builds fine but never boots" symptom. Always build with
> `--sysbuild` and flash with `west flash`.

The board definition's default runner uses OpenOCD's CMSIS-DAP path. Its
`support/openocd.cfg` sources the generic `interface/cmsis-dap.cfg` without
filtering on VID:PID, so with several CMSIS-DAP adapters attached OpenOCD binds
to whichever it finds first — unplug the others, or select one explicitly with
an `adapter usb location`/`-i` argument.

Do **not** use `pyocd` on the current silicon: it aborts during APPROTECT
recovery with `Memory transfer fault @ 0x00ffc31c-0x00ffc31f`. CMSIS-DAP
(OpenOCD) is the supported path. The board's `board.cmake` registers exactly
three runners — `openocd` (the default), `jlink` and `nrfutil` — so
`west flash --runner probe-rs` and `--runner pyocd` are not available for this
board however the probe is attached.

### Serial console over the same USB cable

The on-board SAMD11 also exposes a **USB CDC ACM serial port** and bridges it to
the SoC's `uart20`, so application `printk()` and Zephyr logs appear on the host
over the same USB-C cable used for flashing — no second adapter needed. It runs
at **115200 8N1** and enumerates on Linux as `/dev/ttyACM0` (the index can
differ when other ACM devices are attached).

```bash
# Confirm which ACM node is the Seeed on-board debugger (VID 2886)
udevadm info -q property -n /dev/ttyACM0 | grep -E 'ID_VENDOR_ID|ID_MODEL|ID_SERIAL'
# ID_VENDOR_ID=2886  → Seeed XIAO nRF54LM20A on-board debugger

picocom -b 115200 /dev/ttyACM0      # or: screen /dev/ttyACM0 115200
```

On **macOS** the same port appears as `/dev/cu.usbmodem*` — there is no
`/dev/ttyACM0`, so a copied-and-pasted `/dev/ttyACM0` fails or silently binds
nothing. List the ports first and pick the Seeed one; note that the board
presents both a CDC ACM data port and the CMSIS-DAP interface, so more than one
entry can appear:

```bash
ls /dev/cu.usbmodem*
picocom -b 115200 /dev/cu.usbmodemXXXX
```

The startup banner
(`[HiveInside] nrf54lm20a fw <version> | USB + HiveHub BLE beacon`) prints **once
at boot**, followed by a readout block every measurement cycle, so if the monitor is
opened afterwards, press **RST** with it connected to see the banner and the
first readout. The console is a plain polled UART, so the firmware never blocks
on a missing terminal — it boots and keeps sampling regardless. (The nRF54's
native `usbhs` is not wired to the port — the SAMD11 owns it — so the console
must ride the debugger's UART bridge rather than a native USB-CDC device on the
nRF54.)

### Optional: using a XIAO RP2040 as an external CMSIS-DAP probe

The on-board debugger is sufficient for normal use; this is only for boards
whose debugger is unavailable, or for bench setups that prefer an external
probe. A spare XIAO RP2040 works as the SWD probe:

1. Flash it with Raspberry Pi **Debugprobe** firmware: double-tap reset to mount
   the `RPI-RP2` drive, then drag on `debugprobe_on_pico.uf2` (from the
   `raspberrypi/debugprobe` releases). It re-enumerates as a CMSIS-DAP probe
   (`0x2E8A:0x000C`).
2. Wire probe → target (both are 3.3 V, no level shifting):

   | Probe (XIAO RP2040) | Signal | Target (XIAO nRF54LM20A) |
   | ------------------- | ------ | ------------------------ |
   | GP2 (pad D8)        | SWCLK  | SWCLK / SWDCLK           |
   | GP3 (pad D10)       | SWDIO  | SWDIO                    |
   | GND                 | GND    | GND                      |

   Power the target from its own USB (or the probe's 3V3 — not both).
3. Flash the merged image through the external probe with the OpenOCD runner.
   The board registers no `probe-rs` or `pyocd` runner, and the CMSIS-DAP
   interface config does not filter on VID:PID, so unplug the target's own
   debugger (or keep only one adapter attached) to be sure OpenOCD binds to the
   RP2040 (`0x2E8A:0x000C`) rather than to the on-board SAMD11.

On Linux, add a udev rule so the probe is accessible without `sudo`
(`SUBSYSTEM=="usb", ATTRS{idVendor}=="2e8a", MODE="0666"`), then reload rules
and replug.

The nRF54LM20A firmware reads all four sensors (SHT40, IMU, microphone, nPM1300
battery), prints the readout to this serial console, runs the vibration and
acoustic FFT band analysis, broadcasts the HiveHub measurement beacon, and
accepts firmware-over-BLE updates through MCUboot. See
[`firmware-nrf54lm20a/README.md`](../firmware-nrf54lm20a/README.md) for the
readout format, the build details, and the serial-console setup, and
[`ota-over-ble.md`](ota-over-ble.md) for the OTA protocol.

### The `west --sysbuild` build is the flashing path

Because the firmware boots through MCUboot, a bootable device needs both the
bootloader and the signed application, and only `west --sysbuild` produces them
— see the top of this document. Build it in a west workspace that has the XIAO
nRF54LM20A board definition available: the repository's `west.yml` pins an
upstream Zephyr revision carrying it, and an nRF Connect SDK workspace needs the
board added out of tree (see the board-target section below). `west flash`
programs every sysbuild image over the on-board
CMSIS-DAP debugger; with an external probe (below) select the matching runner, e.g.
`west flash --runner jlink`. Those are the only alternatives the board
registers — `openocd`, `jlink` and `nrfutil` — and `jlink` needs a real J-Link
probe.

> ⚠️ **Not** the "nRF Connect SDK **Bare Metal**" option (`nrf-bm`, board
> targets prefixed `bm_`). That is a separate, RTOS-free SDK line built on the
> SoftDevice and raw nrfx drivers — it has no Zephyr kernel, no Zephyr device
> model or devicetree-driven peripherals, and no Zephyr Bluetooth host. This
> firmware is a Zephyr application (`zephyr/kernel.h`, `zephyr/bluetooth/*`,
> `zephyr/drivers/{regulator,i2c,sensor,gpio}.h`, `zephyr/audio/dmic.h`,
> `zephyr/dfu/mcuboot.h`, plus the board overlays), so it cannot build there at
> any version. Use upstream Zephyr or the RTOS-based nRF Connect SDK. Note also
> that `bm_nrf54lm20dk` is Nordic's nRF54LM20 **DK**, a different board from the
> Seeed XIAO nRF54LM20A Sense this firmware targets.

#### The board target is missing from an nRF Connect SDK workspace

`xiao_nrf54lm20a` ships in **upstream Zephyr**, and only on `main` — no tagged
Zephyr release up to v4.4.2 contains `boards/seeed/xiao_nrf54lm20a/`, which is
why this repository's `west.yml` pins a `main` commit rather than a release.
The nRF Connect SDK uses its own Zephyr fork (`nrfconnect/sdk-zephyr`), which
does **not** carry it — not on `main`, `v3.2-branch` or `v3.1-branch` — so it
never appears in the VS Code extension's board-target dropdown, however new the
SDK is. Only Nordic's own `nrf54lm20dk` is there. Nothing is broken; the
definition is simply absent.

Two ways forward:

* **Build against upstream Zephyr** — `west init -m <this repo>` gives you a
  workspace at the pinned revision. This is the path the rest of this document
  describes and needs no extra setup.
* **Add the board out-of-tree to the NCS workspace.** Copy the whole
  `boards/seeed/xiao_nrf54lm20a/` directory out of upstream Zephyr into a board
  root of your own, keeping the `boards/<vendor>/<board>/` structure:

  ```
  my-boards/
  └── boards/seeed/xiao_nrf54lm20a/     ← the upstream directory, unmodified
  ```

  Then point the build at the directory that *contains* `boards/` — not at the
  board directory itself:

  ```bash
  west build --sysbuild -b xiao_nrf54lm20a/nrf54lm20a/cpuapp \
    path/to/firmware-nrf54lm20a -- -DBOARD_ROOT=/abs/path/to/my-boards
  ```

  In the VS Code extension the same value goes in the nRF Connect **board roots**
  setting, after which the target shows up in the dropdown. Use an absolute path:
  sysbuild resolves relative `*_ROOT` variables against the application
  directory, which is rarely what you mean.

  The copy is self-contained: `seeed_xiao_connector.dtsi` lives inside the board
  directory, and the SoC-level includes it pulls in
  (`nordic/nrf54lm20a_cpuapp.dtsi`, `vendor/nordic/nrf54lm20_a_b_cpuapp_partition.dtsi`)
  are both present in `sdk-zephyr`. Expect to re-sync the copy whenever upstream
  changes the board — this repo's `ncs_fixups.overlay` already exists because the
  two trees do not always agree.

Two failure modes of the VS Code route are worth recognising, because neither is
caused by the board files:

* **"Loading boards…" that never finishes, or an error about an unrelated SoC**
  (`The SoC stm32c5a3xx was not found in the SDK`). Adding a board root makes the
  extension re-scan every board it knows about, and it trips over its own stale
  board/SoC cache — the message says as much ("could be a result of the `west
  update` of the SDK that cleared the SoC cache"). Restart VS Code, or have the
  extension regenerate the cache; the STM32 name is noise, not a hint.
* **A build that fails "because of the Bare Metal SDK" after switching the SDK
  in the dialog.** The selected SDK is baked into the build configuration and
  into `build/CMakeCache.txt` when it is first created. Changing the dropdown
  does not retarget an existing configuration — delete the build configuration
  and its `build/` directory, then create it again against the RTOS-based SDK.

None of this affects the command line. `west build --sysbuild` from a plain
`zephyrproject` workspace is the reference path and stays the quickest way to a
known-good image.

#### If the MCUboot image fails to link

A `--sysbuild` build that dies while linking `mcuboot/zephyr/zephyr_pre0.elf`
with `undefined reference to z_impl_k_mutex_lock` / `k_work_submit` /
`z_impl_k_usleep` (usually preceded by the Kconfig warning `I2C ... was assigned
the value 'n' but got the value 'y'`) is the board's power-management drivers
leaking into the bootloader: MCUboot is built single-threaded on Nordic SoCs,
but the XIAO board tree enables `CONFIG_REGULATOR` plus the `power_en` regulator
and the nPM1300 on a bit-banged I²C bus for *every* sysbuild image, and those
drivers need the kernel mutex/work-queue APIs. `sysbuild/mcuboot.conf` turns
`CONFIG_REGULATOR` and `CONFIG_MFD` off for the bootloader image to prevent
this; if you see the error, check that fragment is being picked up (it must sit
next to the application, i.e. `firmware-nrf54lm20a/sysbuild/mcuboot.conf`) and
rebuild with `--pristine`. The failure is not host- or toolchain-specific, and
a plain `west build` does not reproduce it — it never builds MCUboot.

#### Device is silent after flashing (no console, no BLE)

The firmware prints its banner as the very first statement of `main()`, before
touching any sensor, and starts advertising a few lines later. Missing sensors
never cause silence — an unconnected SHT40 just prints `climate : n/a`. So *no
console output **and** no advertising* means the application is not running at
all, and the fault is in the boot chain rather than in the application. Work
through it in this order:

1. **Is the console itself proven?** Check the port name (macOS uses
   `/dev/cu.usbmodem*`, not `/dev/ttyACM0`) and press **RST** with the monitor
   already attached — the banner prints once at reset and is easy to miss.
   Silence on BLE too makes a pure console problem unlikely, but this is the
   cheapest check.
2. **Did both images reach the chip?** Run `west flash` against the top-level
   sysbuild build directory, not a sub-image directory, and read its output: it
   should program two images. Re-flash explicitly with
   `west flash --domain mcuboot` and `west flash --domain firmware-nrf54lm20a`
   if in doubt. An application alone at slot 0 with nothing at `0x0` faults
   before `main()` and is completely silent — this is the same brick the
   non-sysbuild warning above describes.
3. **Make MCUboot talk.** `sysbuild/mcuboot.conf` disables the bootloader's
   console for size, which also means a bootloader that refuses to start slot 0
   fails *silently*. Temporarily comment out the `CONFIG_SERIAL=n` /
   `CONFIG_CONSOLE=n` / `CONFIG_UART_CONSOLE=n` lines there, add
   `CONFIG_MCUBOOT_LOG_LEVEL_INF=y`, rebuild with `--pristine` and re-flash.
   MCUboot then reports on `uart20` whether it found and validated a slot-0
   image. A signature or image-magic complaint points at the signing key; no
   MCUboot output at all points back at step 2.
4. **Check the signing key matched.** The application must be signed with the
   key the bootloader was built with. Zephyr does *not* fail the build when the
   application has no signing key — `cmake/mcuboot.cmake` only warns that the
   result "will not be bootable by MCUboot unless it is signed manually", and
   `west flash` then programs an unsigned image that MCUboot silently rejects.
   Confirm `build/firmware-nrf54lm20a/zephyr/zephyr.signed.hex` exists and that
   the configure log names the same key file for both images. See the next
   section for how to tell the two apart.

#### `E: Image in the primary slot is not valid!`

With the bootloader console enabled (step 3 above) a rejected application looks
like this:

```
I: Starting bootloader
I: Primary image: magic=unset, swap_type=0x1, copy_done=0x3, image_ok=0x3
I: Boot source: none
E: Image in the primary slot is not valid!
E: Unable to find bootable image
```

`magic=unset` and `image_ok=0x3` are **not** the problem — those describe the
image *trailer*, which an SWD-flashed image legitimately does not have, and
MCUboot boots such an image happily. The failure is `boot_validate_slot()`
rejecting slot 0, which has exactly two causes: the header/signature does not
verify against the key built into the bootloader, or the bytes on the chip are
not the bytes `imgtool` produced. Two commands separate them:

```bash
# (a) Is the image itself validly signed with the bootloader's key?
#     Default sysbuild config uses MCUboot's RSA-2048 development key.
cd <west-topdir>
python bootloader/mcuboot/scripts/imgtool.py verify \
  -k bootloader/mcuboot/root-rsa-2048.pem \
  <build>/firmware-nrf54lm20a/zephyr/zephyr.signed.bin

# (b) Do the bytes on the chip match the hex? (openocd runner only)
west flash --domain firmware-nrf54lm20a --verify
```

If (a) fails, the build is at fault — compare the two images' Kconfig, which is
where a signing-type or key mismatch shows up:

```bash
grep -E 'MCUBOOT_SIGNATURE_KEY_FILE|MCUBOOT_GENERATE_UNSIGNED_IMAGE|ROM_START_OFFSET|MCUBOOT_BOOTLOADER_MODE' \
  <build>/firmware-nrf54lm20a/zephyr/.config
grep -E 'BOOT_SIGNATURE_TYPE|BOOT_SIGNATURE_KEY_FILE|BOOT_VALIDATE_SLOT0|BOOT_SWAP|SINGLE_APPLICATION_SLOT' \
  <build>/mcuboot/zephyr/.config
```

The bootloader and the application must agree on the signature type and the key,
and on the MCUboot mode. Sysbuild derives both sides from the same
`SB_CONFIG_BOOT_SIGNATURE_TYPE_*` / `SB_CONFIG_BOOT_SIGNATURE_KEY_FILE` (default:
RSA with `$(ZEPHYR_MCUBOOT_MODULE_DIR)/root-rsa-2048.pem`), so a mismatch means
something overrode one side — most often a `CONFIG_BOOT_*` line added to
`sysbuild/mcuboot.conf`, which changes only the bootloader and leaves the
application signed the old way. Set signing options in `sysbuild.conf` as
`SB_CONFIG_*` instead, so both images move together.

If (a) passes but (b) fails, the image is good and the programming step is at
fault — see the next section, which is the known cause on this board.

#### Known bug: the OpenOCD RRAM loader drops the last partial write

**Symptom.** `imgtool verify` says the image is fine, but `west flash --verify`
reports a handful of `0xff` bytes at the very end of the image:

```
Error: checksum mismatch - attempting binary compare
diff 0 address 0x00035130. Was 0xff instead of 0xf3
...
No more differences found.
```

**Cause.** The board's flash loader in
`boards/seeed/xiao_nrf54lm20a/support/openocd.cfg` is:

```tcl
proc nrf54lm20a-load {file} {
    mww 0x5004e500 0x101
    load_image $file
}
```

`0x5004e500` is `RRAMC.CONFIG`; `0x101` sets `WEN=1` **and a one-line (16-byte)
write buffer**. `load_image` then writes the image, and the proc stops — it never
commits the buffer. The nRF54L RRAM controller only writes a 128-bit line out
when that line fills, so whatever does not reach a 16-byte boundary is left in
the buffer and never lands in RRAM.

In the build this was diagnosed on, the application image was 151864 bytes;
`151864 mod 16 = 8`, so the final **8** bytes — the tail of the signature TLV —
were silently dropped. MCUboot then reads
a truncated signature and reports `E: Image in the primary slot is not valid!`.
Zephyr's own RRAM driver gets this right: `soc_flash_nrf_rram.c` has a
`commit_changes()` that triggers `NRF_RRAMC_TASK_COMMIT_WRITEBUF` whenever the
write length is not a multiple of the buffer size. The OpenOCD script has no
equivalent. This is upstream board support, not a HiveInside bug, and it affects
any image whose length is not 16-byte aligned.

**Fix.** Disable the write buffer in that proc — one character, and it needs no
register offsets:

```tcl
proc nrf54lm20a-load {file} {
    mww 0x5004e500 0x1     ;# WEN=1, write-buffer size 0 -> every write commits
    load_image $file
}
```

Flashing gets slower, and correct. Keeping the buffer means flushing it after
`load_image`, either by triggering `TASKS_COMMITWRITEBUF` or by reading back the
last written byte — the Product Specification commits a line on "a read
operation from a 128-bit word line in the buffer that has already been written
to", which is the fallback Zephyr's driver uses when the commit task is
unavailable.

**Re-flash both images afterwards**, not just the application. MCUboot is written
in three sections of 34636, 2720 and 60 bytes; the first and last are also not
16-byte aligned, so up to 12 bytes are missing from each. It boots regardless —
those bytes happen not to be on any path that matters — but the bootloader on the
device is not the bootloader that was built. Confirm with:

```bash
west flash --domain mcuboot --verify
west flash --domain firmware-nrf54lm20a --verify
```

See [`ota-over-ble.md`](ota-over-ble.md) for the firmware-over-BLE protocol and
the production release/recovery checklist.

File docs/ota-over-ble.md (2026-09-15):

# Firmware-over-BLE (OTA) for HiveInside

HiveInside has no WiFi — it is a battery-powered BLE-only sensor. HiveScale is
the only node on the network with internet access, so it acts as the OTA relay:

```
backend (HTTPS .bin + CRC-32)  ──►  HiveScale  ──(BLE GATT)──►  HiveInside
        firmware_releases             (WiFi)        OTA service     (dual OTA slots)
```

This mirrors the way HiveScale already relays a BeeCounter image over I²C
(`updateBeeCounter` / `bee_counter_client`); only the last-mile transport differs
(GATT writes instead of I²C registers).

## Why a streaming relay

Firmware images may be too large for the relay to retain alongside its normal
workload. The HiveScale ESP32 (WROOM, no PSRAM) cannot buffer that in RAM, so
HiveScale **streams** the HTTPS download
straight into the GATT characteristics a chunk at a time and never holds the
whole image. HiveInside likewise buffers nothing: each chunk is written directly
to its inactive OTA slot. Nothing is committed until the final CRC check passes,
so a dropped or corrupted transfer always leaves the device on its old image.

## Partition layout and release artifact

The Seeed nRF54LM20A board definition already partitions its 2 MiB RRAM for
MCUboot: a 64 KiB boot partition, 449 KiB application slot 0, a matching 449 KiB
slot 1, corresponding non-secure slots, and storage. HiveInside deliberately
uses that board layout rather than carrying a second, easily-diverged overlay.
The application must remain below the 449 KiB slot limit.

`sysbuild.conf` enables MCUboot and `CONFIG_BOOTLOADER_MCUBOOT` causes the
application to be linked with its MCUboot header. Only a `west --sysbuild` build
produces the signed release artifact `build/<app>/zephyr/zephyr.signed.bin`;
**that signed file**, including its MCUboot header, is the object uploaded to the
backend and whose CRC/size are sent in BEGIN.

The build also drops a byte-identical copy beside it under a name carrying the
firmware version and the image variant, for example:

```
hiveinside-nrf54lm20a-v0.4.5-bringup.signed.bin     # normal build, console on
hiveinside-nrf54lm20a-v0.4.5-lowpower.signed.bin    # docs/low-power.md profile
```

Upload that copy rather than `zephyr.signed.bin`. Every build configuration
writes the same `zephyr.signed.bin` filename, so once two of them leave their
build directories nothing distinguishes them — and serving the bring-up image to
a sealed hive fails silently, because it boots and advertises exactly like the
image it replaced. The variant suffix is derived from `CONFIG_SERIAL` in the
image that was actually built, not from how the build was requested. The version comes from
`HIVEINSIDE_FW_VERSION_MAJOR`/`_MINOR`/`_PATCH` in `src/hive_config.h` — the
same numbers the node advertises — so bumping them there moves the artifact
name and the on-air version together.

The HiveHub dashboard reads that name when the file is picked in its firmware
upload form: it selects the `HiveInside` target and fills the version in from the
`v<version>` token, ignoring the variant suffix and `.signed`. So
`hiveinside-nrf54lm20a-v0.4.5-lowpower.signed.bin` uploads as HiveInside `0.4.5`
with nothing typed in — another reason to upload the stamped copy rather than
`zephyr.signed.bin`, whose name says nothing and fills in nothing.

> A build without `--sysbuild` never emits a signed image or a bootable merged
> hex — it builds the application alone. Build and flash releases with
> `west --sysbuild` (see [`flashing.md`](flashing.md)).

## GATT protocol

All OTA characteristics live in the custom HiveInside service
`8e8b0001-7a1c-4b9e-9a2f-1d6e0b9c1a01`, implemented in
[`firmware-nrf54lm20a/src/ota.c`](../firmware-nrf54lm20a/src/ota.c). UUIDs and
framing must stay in sync with HiveScale `firmware/src/ble_sensor.cpp` (the
`HI_OTA_*` constants). These three characteristics are the **only** GATT
attributes the device exposes — there is no measurement characteristic; the
measurement is read from the advertisement (see
[`../firmware-nrf54lm20a/README.md`](../firmware-nrf54lm20a/README.md)).

| Characteristic | UUID | Props | Payload |
|---|---|---|---|
| OTA control | `8e8b0010-…` | Write | framed command (see below) |
| OTA data | `8e8b0011-…` | Write / Write-NR | raw firmware bytes, in order |
| OTA status | `8e8b0013-…` | Read / Notify | `state(1) + received(4 LE) + error(1) + errno(1)` |

### Control frames (first byte = opcode)

| Opcode | Bytes | Meaning |
|---|---|---|
| `0x01` BEGIN | `0x01 + size(4 LE) + crc32(4 LE)` | initialize slot stream; store expected CRC |
| `0x03` END | `0x03` | verify size + CRC, request test upgrade, reboot |
| `0x04` ABORT | `0x04` | cancel transfer; stay on current image |

### Status `state` byte

| Value | Meaning |
|---|---|
| `0x00` | idle |
| `0x01` | receiving |
| `0x02` | done (verified, rebooting) |
| `0x10` | begin failed |
| `0x11` | sequence failed |
| `0x12` | slot write failed |
| `0x13` | CRC failed |
| `0x14` | size failed |
| `0x15` | end/finalization failed |

### Status `errno` byte

The seventh byte is the errno of the last failed flash operation — the `rc`
from `flash_img_init()` (`0x10`), from the rejected `flash_img_buffered_write()`
(`0x12`), or from the final flush (`0x15`) — clamped into a signed byte, and `0`
when nothing has been recorded. It exists because the
[`low-power`](low-power.md) profile that actually gets deployed has no console,
so without it a field failure can only ever say "flash write failed", which does
not distinguish a slot that is too small (`-EINVAL`) from a radio timeslot that
never arrived (`-ETIMEDOUT`).

Added in firmware 0.4.7. It is appended after the original six bytes rather than
replacing anything, so a relay that reads six bytes keeps working unchanged;
HiveHub reads whatever length the device returns and treats a missing seventh
byte as "not recorded".

### CRC-32

IEEE 802.3 (reflected poly `0xEDB88320`, init/final `0xFFFFFFFF`) — identical to
`zlib.crc32` on the backend and `beecnt::crc32_buf` on HiveScale, so the value the
backend computes at release time is verified unchanged on the device. End-to-end:
if HiveScale's download is corrupt, the device's CRC check fails and it aborts —
HiveScale cannot brick the sensor.

## Transfer sequence

1. Backend has an active `firmware_releases` row with `target = 'hiveinside'`
   (filename + crc32). An operator queues the update:
   `POST /api/v1/devices/{device_id}/commands/update-hiveinside?slot=1`.
2. On its next command poll HiveScale receives `update_hiveinside` with
   `{ slot, url, crc32 }`, resolves the slot's paired BLE MAC
   (`bleSensorMac0`/`bleSensorMac1`), and calls `updateHiveInside()`.
3. HiveScale opens the HTTPS GET, then opens the BLE session
   (`blesensor::otaBegin` → locate, connect, MTU exchange, BEGIN), and pumps the
   body into the DATA characteristic (`otaWrite`). Each DATA write is
   flow-controlled: the device only sends the ATT write-response after it has
   flashed the chunk.
4. HiveScale sends END (`otaFinish`) and polls STATUS. The device verifies size +
   CRC, flushes `flash_img`, requests `BOOT_UPGRADE_TEST`, and reports `done`.
5. A delayed Zephyr work item reboots HiveInside into the new slot ~1.5 s later (after the
   central has had a chance to read `done`).

The nRF54 advertises continuously with legacy connectable/scannable `ADV_IND`
at the same interval used by the former `ADV_SCAN_IND` beacon. Its primary
manufacturer payload and name+identity scan response are unchanged. A connection
which does not send BEGIN within six seconds is disconnected, a transfer that
goes `HIVE_OTA_STALL_TIMEOUT_MS` (30 s) without a single DATA write is
abandoned, and a short link supervision timeout releases a vanished central.
`ota_is_active()` gates the sensor loop while connected or transferring.

## Safety and lifecycle

DATA callbacks call `flash_img_buffered_write()` synchronously before returning,
so HiveHub's write-with-response is flash-level flow control. CRC accumulation
starts at literal zero and chains `crc32_ieee_update()`, matching
`zlib.crc32`. END checks the exact received size and CRC before marking slot 1
pending. It then schedules a reset 1.5 seconds later, leaving time to read DONE.
The new image is a MCUboot **test** upgrade. It confirms itself only after one
complete sensor-read cycle and a successful BLE measurement publication; a
failure before that point leaves the image unconfirmed so MCUboot can revert it
on the next reset. A test image does not revert merely because a peripheral is
absent: individual sensor drivers deliberately degrade to `n/a`, while successful
BLE publication is the health gate.

Every state that gates the sensor loop is bounded, which matters because a
gated node is off the air entirely: it takes no measurements, and because it is
connected it is not advertising either, so HiveHub sees nothing at all. The
watchdog cannot rescue it — the OTA path feeds the watchdog deliberately, since
a real upload takes minutes. The bounds are: six seconds connected without
BEGIN (arm timeout), thirty seconds receiving without a DATA write (stall
timeout), and 1.5 seconds in `done` before the reboot fires. A transfer that is
slow but still progressing is never cut short, and it cannot run forever either:
`received` is capped at the size declared in BEGIN, after which any further DATA
write is rejected.

This health gate proves that the image can boot, sample, and advertise; it cannot
prove that a future central can discover and complete another OTA session. A
regression isolated to the OTA GATT path can therefore still require SWD recovery.
Confirmation is attempted at most once per boot so a persistent trailer-write
failure cannot cause periodic flash writes indefinitely.

To bound how long an unhealthy image can run before it rolls back, a test image
arms a confirmation deadline at boot (`OTA_CONFIRM_DEADLINE_MS`, 120 s). If it has
not confirmed within that window — radio never came up, the main loop wedged in a
sensor driver, or the trailer write kept failing — it reboots so MCUboot reverts
to the previous image, rather than running unconfirmed until the next unrelated
reset (up to a full `MEASURE_INTERVAL_MS` away). The deadline is armed only when
MCUboot reports a real test swap (`BOOT_SWAP_TYPE_REVERT`); a directly
SWD-flashed image has no rollback target, is never armed, and cannot boot loop.

Only the three OTA characteristics are exposed. They require neither link
encryption nor the audio service's HMAC, and the node advertises connectably at
all times. Image-signature trust is therefore the deployment security boundary:
any nearby central can upload bytes, but only a project-signed image may boot.
The filter-accept-list TODO in `ota_init()` is intentionally still in place; it
requires a future, coordinated HiveHub bonding change.

## Build

Only a sysbuild build produces a release artifact: `west build --sysbuild -b
xiao_nrf54lm20a/nrf54lm20a/cpuapp -d debug firmware-nrf54lm20a`. A build without
`--sysbuild` compile-checks the application and stops there. Release automation
must publish the generated **signed** application binary, never the raw
`zephyr.bin`.

## Troubleshooting: the relay runs but the version never changes

The most confusing OTA failure reports no error anywhere. The relay completes,
the backend shows the update queued or sent, and the node keeps advertising the
old version. Four different causes produce that identical picture, so work down
the list rather than guessing.

Watch the node's serial console across a relay attempt — build the normal
(console) image for this, not the [`low-power`](low-power.md) profile, which has
no output at all. A healthy transfer prints:

```
[OTA] central connected; waiting for BEGIN
[OTA] slot 1 offset=0x<...> size=<n>
[OTA] flash_img_init rc=0
[OTA] BEGIN size=<n> crc=0x<...>
[OTA] image verified; test upgrade requested
[OTA] rebooting into test image
... reboot ...
[HiveInside] nrf54lm20a fw <new version> | USB + HiveHub BLE beacon
[OTA] test image confirmed after first complete cycle
```

Where it stops tells you which of these you have:

0. **`BEGIN` then silence, and the node disappears from HiveHub entirely.**
   The relay opened a session and stopped writing. Until the stall timeout was
   added the node stayed gated indefinitely — no measurements, no advertising,
   for as long as the relay held the link. Recover by making the relay drop the
   connection (resetting HiveScale is enough) or by power-cycling the node;
   nothing is damaged and the node stays on its old image. Firmware carrying the
   stall timeout abandons the transfer itself after thirty seconds and prints
   `[OTA] no data for 30000 ms; abandoning transfer`.

1. **Nothing at all.** The relay never opened a BLE connection. The image never
   reached the node, so nothing on the node can report it. This is a relay-side
   or pairing problem — check that the node's identity address matches the slot
   the relay is targeting.

2. **`connected` then `connection not armed; disconnecting`.** The central
   connected but never sent BEGIN within six seconds. The relay reached the node
   and gave up, usually because the release row or the download was missing on
   the backend side.

3. **`BEGIN` then an error state.** The node rejected the transfer and set an
   error in the STATUS characteristic (`0x10`–`0x15`, table above). If the
   backend does not surface STATUS, this looks like silence from the outside.
   `0x13` CRC and `0x14` size mean the bytes that arrived are not the bytes the
   release row describes. For `0x10`, the console prints the resolved slot 1
   offset and size followed by `flash_img_init rc=<errno>`. For `0x12`, it
   prints `flash write failed offset=<n> len=<n> rc=<errno>` at the rejected
   DATA write. A failure while flushing the final partial block reports `END
   flash flush failed` with its offset and errno before setting `0x15`. Preserve
   those exact values: they distinguish alignment/range (`-EINVAL`) from flash
   protection (`-EACCES`) and device or hardware errors. This diagnostic build
   must be installed over SWD; it cannot be rolled out through the broken OTA
   path.

   The one instance of `0x12` seen in the field is worth recognising on sight,
   because the numbers are always the same and they look like a link problem
   rather than a flash one. See the section below.

4. **The full happy trace, then the old version comes back.** The image
   installed and MCUboot reverted it, or it never really differed:

   * **Wrong artifact.** Uploading `zephyr.bin` instead of the signed image
     gives a payload MCUboot cannot validate. The node reports `done` and
     reboots, MCUboot rejects the slot, and the old image runs again. Upload the
     version-stamped `…signed.bin` described above.
   * **Rollback.** A test image confirms only after one complete sensor cycle
     *and* a successful BLE publication. If it boots but cannot advertise, it
     never confirms and reverts within `OTA_CONFIRM_DEADLINE_MS` (two minutes).
     The banner line appears with the new version, then the node resets back.
   * **The version was never bumped in the firmware.** The number the backend
     sees comes from `HIVEINSIDE_FW_VERSION_MAJOR`/`_MINOR`/`_PATCH` in
     `src/hive_config.h`, not from the version typed into the upload form. If
     the binary was built without changing those, the OTA succeeded and the node
     is genuinely running the new image — it just advertises the old number. The
     banner line above is the giveaway: it shows the same version before and
     after. Bump the three numbers, rebuild, and re-upload.

## Troubleshooting: `0x12 flash write failed` at exactly 488 bytes

Firmware before 0.4.7 fails every OTA the same way, and the signature is exact:

```
[HI-OTA] connected: MTU=247 chunk=244 image=141084 bytes crc=0x...
E NimBLERemoteValueAttribute: << writeValue failed, rc: 270
[HI-OTA] DATA write failed after 488 bytes this buffer (488 total)
[HI-OTA] device rejected the stream: state=0x12 err=0x12 received=488 (flash write failed)
```

with the node's own console showing only

```
[OTA] BEGIN size=141084 crc=0x...
[OTA] central disconnected (0x08)
```

Read the numbers rather than the words. BEGIN succeeds because it touches no
flash beyond `flash_img_init()`. The first two 244-byte DATA writes succeed
because they only fill `stream_flash`'s 512-byte buffer. The third fails, at
488 = 2 × 244 received, because it is the write that first fills that buffer and
so triggers the **first real `flash_write()` of the whole transfer**. NimBLE's
`rc: 270` is `0x10E`, i.e. ATT error `0x0E` "unlikely error" — exactly what
`data_write()` returns when `flash_img_buffered_write()` fails. The `0x08` on
the node is an HCI link supervision timeout, not a clean teardown.

The cause is not the flash and not the radio separately, but the interaction.
Writing RRAM with the controller running is a scheduled operation: upstream
Zephyr's link layer makes `SOC_FLASH_NRF_RADIO_SYNC_TICKER` the RRAM driver's
default, so every `flash_write()` runs inside a ticker-scheduled radio timeslot.
At the driver's default `CONFIG_NRF_RRAM_WRITE_BUFFER_SIZE=1` that timeslot is
500 µs long, and `nrf_flash_sync_set_context()` derives the flash ticker's period
as `slot - 1700 µs` — an unsigned subtraction that wraps. On top of that,
`nrf_flash_sync_check_time_limit()` returns true unconditionally on nRF54Lx, so
one timeslot moves at most one 128-bit line: 16 bytes, meaning a single 512-byte
flush would need 32 consecutive slots on that broken schedule. The write fails,
and the radio events the flash ticker aborted along the way drop the link.

The fix is two lines of `prj.conf`, documented in place there:
`CONFIG_NRF_RRAM_WRITE_BUFFER_SIZE=32` (the maximum — the period becomes
8000 − 1700 = 6300 µs and one timeslot carries a full 512 bytes) paired with
`CONFIG_IMG_BLOCK_BUF_SIZE=512`, so every flush is one `flash_write()` that
completes in one timeslot. Do not raise the image buffer past 512 without
raising the write buffer with it; that silently restores the multi-timeslot path.

Because the failure happens on the very first flash write, no partial image is
ever written and the node stays on its old firmware. The fix has to be installed
over SWD — a device that cannot complete an OTA cannot receive the fix for it.

## Production release and recovery checklist

The SDK's default MCUboot development key is suitable only for bring-up. It is
publicly known and therefore provides image formatting, **not production
authenticity**. Using a project-owned key is a required deployment step, not an
optional hardening measure. Generate it with MCUboot's `imgtool keygen`, store
the private PEM outside the repository, and select it at the sysbuild level so
MCUboot and application signing cannot diverge:

```bash
python bootloader/mcuboot/scripts/imgtool.py keygen \
  -k /secure/hiveinside-signing.pem -t rsa-2048
west build --pristine=always --sysbuild \
  -b xiao_nrf54lm20a/nrf54lm20a/cpuapp -d build firmware-nrf54lm20a -- \
  -DSB_CONFIG_BOOT_SIGNATURE_KEY_FILE=/secure/hiveinside-signing.pem
```

Keep the key out of build logs, archive its matching public key and the recovery
procedure, and provision the `HIVEINSIDE_SIGNING_KEY_PEM` GitHub Actions secret
before running `.github/workflows/release.yml`; that workflow now refuses to
produce artifacts without it and verifies MCUboot selected it. Changing the key
later requires an SWD recovery image whose MCUboot contains the new public key.

For every release:

1. Start from a clean `west build --pristine --sysbuild ...` build and retain the
   build manifest/configuration alongside the artifact.
2. Check the generated partition report and the signed image size against the
   actual secondary-slot capacity; do not rely only on the nominal 449 KiB figure.
3. Compute the backend size and CRC from the exact signed binary that is
   uploaded (never from `zephyr.bin` or `merged.hex`). Prefer the
   version-stamped copy — `hiveinside-<board>-v<version>-<variant>.signed.bin` —
   so the artifact on the backend still identifies itself after it is detached
   from the build directory, and check its `-bringup`/`-lowpower` suffix is the
   one you intended before publishing.
4. Flash `merged.hex` onto a representative board over SWD, perform a complete
   BLE OTA with the release artifact, and verify the version after reboot.
5. Run a rollback test with an intentionally non-confirming test application and
   keep an SWD mass-erase/reflash path available. BLE OTA cannot recover a device
   whose bootloader, signing key, partition layout, or radio/application startup
   is broken.

Steps 1 and 3 are mechanised: `.github/workflows/release.yml` requires the
project-owned signing-key secret, builds both
variants pristine on a tag, publishes the version-stamped payload together with
a `manifest.txt` carrying each payload's byte size and CRC-32, and attaches the
frozen west manifest and both images' Kconfig so the build can be reproduced.
Steps 2, 4 and 5 still need a person and a board. The workflow fails before the
build rather than publishing an artifact made with the development key.

## Implementation

`firmware-nrf54lm20a/src/ota.c` streams into the board's MCUboot secondary slot,
validates size and CRC, requests a test swap, and self-confirms after a healthy
boot. There is no placeholder or alternative OTA implementation in this
repository.

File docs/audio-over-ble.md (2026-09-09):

# Audio over BLE

*Firmware **0.6.2** or later. 0.6.0/0.6.1 stream the protocol below correctly but
capture only the first few tens of milliseconds of real sound — see [One session
at a time](#one-session-at-a-time).*

HiveInside exposes an authenticated, on-request microphone stream to HiveHub:

```
MSM261 PDM mic -> nRF PDM PCM16 -> 32 KiB ring -> BLE notifications -> HiveHub
                         32 kB/s                 measured 137 kB/s
```

The stream remains raw 16 kHz, 16-bit little-endian mono PCM. The measured 15 ms,
2M-PHY link carries 137 kB/s, over four times the 32 kB/s capture rate, so a
codec would add failure state without fitting a constrained pipe. Streaming uses
about 32 KiB rather than the 320 KiB or more needed for a useful whole clip.

## GATT service

All UUIDs end in `-7a1c-4b9e-9a2f-1d6e0b9c1a01`.

| Characteristic | UUID prefix | Properties | Value |
|---|---|---|---|
| Service | `8e8b0002` | primary | — |
| CTRL | `8e8b0020` | write | commands below |
| DATA | `8e8b0021` | notify | sequenced PCM packets |
| STATUS | `8e8b0023` | read, notify | 30-byte session record |

Subscribe to DATA before START. A DATA notification is `seq(2 LE), flags(1),
reserved(1), PCM16`. The PCM portion is `min(MTU-3-4, 240)` bytes, rounded down
to an even length. Sequence numbers are free-running unsigned 16-bit values.
Flag bit 0 marks the final, header-only packet. Bit 1 says whole audio blocks
were dropped immediately before this packet; do not splice across that hole.

CTRL commands are:

| Opcode | Exact bytes | Meaning |
|---|---|---|
| `0x01` START | `op, duration_ds(2 LE), rate_code, format, gain_db, hmac(8)` | authenticate and capture |
| `0x02` STOP | `op` | end the current stream |

`duration_ds=0` means live/open-ended. Every session still stops at 60 seconds.
The only rate code is 0 (16 kHz); the only implemented format is 0 (PCM16 LE
mono). Format 1 is reserved for ADPCM and returns unsupported-format. Gain is a
signed byte clamped to -20..+20 dB, applied before transmission with saturation.

STATUS is always exactly 30 bytes:

| Offset | Size | Field |
|---:|---:|---|
| 0 | 1 | state: IDLE `00`, ARMED `01`, STREAMING `02`, DONE `03` |
| 1 | 1 | error |
| 2 | 8 | current authentication nonce |
| 10 | 4 | transmitted PCM bytes, LE |
| 14 | 4 | elapsed milliseconds, LE |
| 18 | 4 | bytes lost to ring overrun, LE |
| 22 | 4 | IEEE CRC-32 of transmitted, post-gain PCM, LE |
| 26 | 2 | sample rate (16000), LE |
| 28 | 1 | format (0) |
| 29 | 1 | clipped samples as integer percent |

Errors are bad parameters `10`, authentication `11`, busy `12`, microphone
`13`, DATA not subscribed `14`, notification stall `15`, and unsupported format
`16`. STATUS notifies on each state change and at completion.

## Authentication and client sequence

### Provisioning the key

The node and HiveHub share one random 32-byte key. They want it in different
notations — a C array here, a hex string on the hub — so generate it once and
print both forms rather than converting by hand:

```bash
KEY=$(openssl rand -hex 32)
echo "HiveHub  secrets.h:  #define HIVEINSIDE_AUDIO_PSK_HEX \"$KEY\""
echo "HiveInside audio_secret.h:"
echo "$KEY" | sed 's/../0x&, /g' | fold -sw 48 | sed 's/^/\t/;s/ $//'
```

Copy `src/audio_secret.example.h` to `src/audio_secret.h` (gitignored) and paste
the array rows in place of the zeros:

```c
#pragma once
#include <stdint.h>
static const uint8_t hive_audio_psk[32] = {
	0x40, 0xd8, 0x13, 0xad, 0x97, 0x4c, 0x15, 0x06,
	0x27, 0x03, 0xa0, 0x4e, 0x1f, 0xa3, 0x67, 0x25,
	0xf7, 0x09, 0x33, 0x30, 0xa8, 0xd3, 0xd1, 0x01,
	0x81, 0xfc, 0xdf, 0xe5, 0x59, 0x19, 0x42, 0x6b,
};
```

The hub takes the same key as the 64-character hex line in its
`firmware/include/secrets.h`; HiveHub's `docs/audio-recording.md` covers that
side, including the fact that its `FORCE_RESEED` flag is **not** involved — that
only re-seeds a claim code into NVS, while the audio key is compiled in and read
afresh at every session.

A missing or all-zero key fails closed: every START is refused with
authentication error `11` and, on a console build, a line saying the key is
absent. That is deliberate. The alternative is an in-hive microphone any BLE
device in range can switch on.

Flash both sides together. The key is checked per session, so in between the two
flashes audio fails authentication while the beacon and its measurements carry on
exactly as before — which is what makes a key mismatch look like a radio problem
rather than a configuration one.

### Client sequence

1. Connect, subscribe to DATA (and optionally STATUS), then read STATUS.
2. Take its fresh eight-byte nonce.
3. Compute `HMAC-SHA256(key, nonce || op || duration_ds_LE || rate_code ||
   format || gain_db)` and append the first eight digest bytes to START.
4. Write START and consume DATA until its final flag; verify byte count and
   CRC against final STATUS. Treat nonzero dropped bytes as an incomplete clip.

The node compares the tag without early exit. A failed attempt rotates the
nonce, so reread STATUS before retrying. The nonce also rotates on connection
and after every completed session.

## One session at a time

The node has **one** PDM controller and **one** switchable sensor rail (LDO1,
plus the P1.12 gate upstream of it), and two things want them: the five-minute
measurement cycle and an audio session. Nothing may run both at once.

Until 0.6.2 that was enforced only by a `link_is_busy()` check at the top of the
measurement loop, which is a decision, not a lock. A cycle that had already
passed that check went on to read the IMU and microphone and then call
`power_sensor_rail_disable()` — underneath a session that had started in the
meantime. The rail went away with the audio still streaming, and because the
"enabled" flag was a plain boolean, the session's own `power_sensor_rail_enable()`
had returned success without doing anything. The result was a full-length
recording of which only the first ~50 ms carried signal; the rest was the ±4 LSB
of an unpowered microphone. The transport reported it as perfectly clean,
because it was: every byte the node sent arrived.

0.6.2 replaces the check with two mechanisms:

* **A session gate** (`link_measurement_begin()` / `link_measurement_end()`, a
  binary semaphore in `link.c`). The measurement cycle holds it from before the
  rail is powered until after it is dropped, so `link_claim()` — and with it
  every START — reports **busy `12`** rather than cutting in. GATT callbacks take
  it with `K_NO_WAIT` and never block on a capture; the main loop waits on it and
  feeds the watchdog while it does, because a session can last a minute.
* **A reference-counted sensor rail.** `power_sensor_rail_enable()` /
  `_disable()` now count users under a mutex, so no holder can switch the rail
  out from under another. `power_init()` owns the boot-time reference and
  `main()` drops it once, which is why the counter starts balanced.

Session setup also moved out of the GATT write callback into the capture thread:
`ctrl_write()` now answers **ARMED**, and the thread powers the rail, waits for
it to settle and starts PDM before publishing **STREAMING**. A client that waits
for STREAMING is therefore waiting for a microphone that is genuinely running.

The visible symptom of the old bug is worth knowing, because it does not look
like a bug in the audio path at all: length, checksum and dropped-byte counters
all come back clean, and only listening reveals that the hive went silent a
twentieth of a second in.

## Bounded states and privacy

The microphone is off unless an authenticated START owns the exclusive link.
OTA and audio cannot overlap, and periodic sensing is held off for the whole of
a session by the gate above (and, conversely, a session cannot start while a
measurement cycle is in flight).
A connection that claims no service is disconnected after 10 seconds. Capture
ends at the requested duration, STOP, disconnect, or the absolute 60-second
cap. Five seconds without a notification completion is a stalled session. Each
end path stops PDM, removes sensor-rail power, publishes final STATUS where the
link remains, and releases ownership. Authentication is application-level
access control; audio is not encrypted unless the BLE connection itself is
secured by the client.

## Troubleshooting

* **Error 14:** subscribe to DATA before START; enabling STATUS alone is not enough.
* **Error 11:** provision a nonzero key on BOTH sides (see [Provisioning the
  key](#provisioning-the-key) — the commonest cause is flashing one device and
  not the other), reread the rotated nonce, and ensure the signed gain byte and
  little-endian duration are included exactly once.
* **Error 16:** request format 0; ADPCM is only a reserved wire value.
* **Short packets:** negotiate ATT MTU 247; smaller MTUs are valid and reduce PCM
  per notification while preserving sample boundaries.
* **Holes or CRC mismatch:** inspect sequence numbers, DATA flag bit 1, final
  `dropped_bytes`, and CRC. Nonzero drops mean the recording is not clean.
* **Error 12 (busy):** a measurement cycle holds the session gate. Cycles are
  short; retry. A `12` that never clears means something claimed the link and
  did not release it — reconnecting rearms the 10-second window.
* **Audio that starts and then goes silent:** the node is running 0.6.0 or
  0.6.1. Update to 0.6.2 — see [One session at a time](#one-session-at-a-time).
  The counters cannot show this: the bytes that arrived are exactly the bytes
  that were sent, they just contain no sound.
* **Error 15:** verify the central negotiated notifications, 15 ms interval,
  251-byte data length and 2M PHY and continues acknowledging controller TX.
* **Disconnect near startup:** complete STATUS/nonce/START within the 10-second
  arm window.

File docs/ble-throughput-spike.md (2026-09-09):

# BLE notification throughput — measurement spike

**Temporary — and now answered.** Everything described here exists to answer one
question for [HiveInside issue #71](https://github.com/MacNite/HiveInside/issues/71)
(record an audio sample on request).

> ## The answer: 137 kB/s
>
> Measured node → XIAO ESP32-C6, 15 ms connection interval, 2M PHY, 251-byte
> PDUs. That is over four times the 32 kB/s a 16 kHz PCM16 microphone produces,
> and roughly a hundred times the OTA relay's ~1.4 kB/s — so the audio feature
> ships **raw PCM16, streamed**, with no codec and no whole-clip buffering. See
> [`audio-over-ble.md`](audio-over-ble.md).
>
> The thresholds table below was written before the run and is left as it was;
> the result cleared its top row by a factor of seventeen. Nothing here needs to
> be re-run, and the spike is now safe to delete — see [Removing it](#removing-it).

The rest of this page is kept as the record of how the number was obtained.

## The question

The audio feature has to move a recording from the node to the HiveHub relay:
peripheral → central, out of RAM, as GATT **notifications**. Nothing in this
firmware does that today, so nothing measures it either.

The only throughput number the project has is the OTA relay's, and on a real
deployment that came out at **≈1–1.5 kB/s** (172 kB image in 120–160 s). If that
were the ceiling for audio, streaming would be dead on arrival — ten seconds of
16 kHz IMA-ADPCM is 80 kB, which would take a minute to ship.

But the OTA path is a poor proxy for an audio stream, in three ways that all
push the same direction:

1. **Wrong direction, wrong primitive.** `gatt_ota.cpp` writes each chunk with
   `response=true` and blocks on the ATT response, so a 244-byte chunk costs at
   least two connection intervals — a hard ceiling near 3 kB/s at the 30–50 ms
   interval `ota.c` requests. Notifications have no per-packet round trip, and
   Zephyr can queue several into one connection event.
2. **Flash writes inside the ATT callback.** `data_write()` calls
   `flash_img_buffered_write()` synchronously before it returns the response —
   deliberately, because that *is* the OTA flow control. On this SoC each
   512-byte flush executes inside a radio timeslot that pre-empts connection
   events (see the `CONFIG_NRF_RRAM_WRITE_BUFFER_SIZE` discussion in
   `prj.conf`). An audio stream touches no flash at all.
3. **WiFi and BLE at once.** The relay holds a TLS download open while writing
   GATT, on one shared 2.4 GHz radio.

So the OTA figure largely measures RRAM write scheduling, not the radio. This
spike measures the radio.

## What it adds

| File | What it is |
|---|---|
| `firmware-nrf54lm20a/src/throughput.c/.h` | GATT service that blasts a counter pattern and logs the negotiated link parameters |
| `firmware-nrf54lm20a/throughput-spike.conf` | Kconfig fragment that compiles it in |
| `tools/throughput/ble_throughput.py` | laptop client (bleak) — upper bound |
| HiveHub `tools/ble-throughput/` | ESP32 client — **the number that decides the design** |

A build that does not apply the fragment is byte-identical with these files
present: `ENABLE_THROUGHPUT_SPIKE` defaults to 0 in `src/hive_config.h` and the
whole module compiles away.

## Protocol

Same UUID family as the OTA service, in the `0x8e8b00fx` range so it cannot
collide with a future audio service.

| Characteristic | UUID | |
|---|---|---|
| CTRL | `8e8b00f1-7a1c-4b9e-9a2f-1d6e0b9c1a01` | write |
| DATA | `8e8b00f2-…` | notify |
| STATUS | `8e8b00f3-…` | read / notify |

```
CTRL   0x01 duration_s payload_len [interval_units]   start a run
       0x02                                           stop early
DATA   seq(4 LE) + filler, payload_len bytes total
STATUS state(1) bytes(4 LE) ms(4 LE) notifs(4 LE) payload_len(1) mtu(2 LE)
```

`interval_units` is in the BLE 1.25 ms unit (12 = 15 ms, 24 = 30 ms) and is
applied by the **node**, via `bt_conn_le_param_update()` — the direction a real
audio session would ask in, and it means the interval can be swept from the
client without a reflash.

The 32-bit sequence number at the head of every notification is what separates
"the link is slow" from "the link is dropping packets": the node reports what it
handed to its controller, the client reports what arrived, and a gap between the
two is loss, not throughput.

## Running it

### 1. Build and flash the spike image

Layer the fragment on `prj.conf` as an **extra** Kconfig fragment — never a base
one (`docs/vscode-build.md` explains why that distinction bites):

```sh
west build --sysbuild -b xiao_nrf54lm20a/nrf54lm20a/cpuapp -d spike \
    firmware-nrf54lm20a -- -DEXTRA_CONF_FILE=throughput-spike.conf
west flash -d spike
```

In VS Code, add a third build configuration named `spike` with
`throughput-spike.conf` in **Extra Kconfig fragments**, exactly as the
`lowpower` configuration is set up.

The console will print, at boot:

```
[TP] BLE throughput spike compiled in — measurement build, NOT for deployment
```

If that line is missing, the fragment did not take and everything below will
measure a device that has no throughput service.

### 2. Laptop first (cheap sanity check)

```sh
pip install bleak
tools/throughput/ble_throughput.py --duration 15 --payload 244 --interval 12
```

This is an **upper bound**: a desktop Bluetooth stack is not the relay's
controller. Its value is diagnostic — if the laptop also sees 1–2 kB/s the limit
is on the node and no amount of work on the hub will help; if the laptop sees
30 kB/s and the ESP32 sees 3, the limit is the relay.

### 3. The ESP32 client (the real answer)

In the HiveHub repository, `tools/ble-throughput/` is a standalone PlatformIO
project — deliberately separate from `firmware/` so it can never be linked into
a hub image. Flash it to a **spare** ESP32:

```sh
pio run -e esp32dev -t upload -t monitor
```

Run it on both boards. The classic ESP32 is BLE 4.2 with **no 2M PHY**; the
ESP32-C6 has it, so the two can legitimately differ by roughly a factor of two.

### 4. Sweep the two knobs that matter

- **Connection interval** — `--interval` / `-DTP_INTERVAL_UNITS`. Try 12 (15 ms)
  against 24 (30 ms).
- **Controller TX buffers** — `CONFIG_BT_BUF_ACL_TX_COUNT` in
  `throughput-spike.conf` (3 is the `prj.conf` value, the fragment ships 6).
  `throughput.c` takes its in-flight credit count straight from this symbol, so
  changing it sweeps notifications-per-connection-event. Raising it costs about
  251 bytes of RAM per buffer — watch the build's RAM report.

### 5. Repeat with WiFi busy

A pass-through streaming design has BLE and WiFi active at the same time. Set
`-DTP_WIFI_LOAD=1` in the ESP32 project (plus SSID, password and a URL to pull)
and re-run. A large gap between the idle and loaded numbers is an argument for
buffering the clip to SD and uploading **after** disconnecting, rather than
streaming straight through.

## Reading the result

Both clients print a verdict, against these thresholds:

| Sustained | What it means for #71 |
|---|---|
| ≥ 8 kB/s | real-time streaming of 16 kHz ADPCM is viable |
| 4–8 kB/s | stream at 8 kHz ADPCM, or buffer the clip at 16 kHz |
| < 4 kB/s | buffer the whole clip on the node; streaming is out |

Also check the console lines the spike logs on connect:

```
[TP] connected: interval=… latency=… timeout=…
[TP] PHY now tx=2 rx=2                    1 = 1M, 2 = 2M, 4 = Coded
[TP] data length now tx=251 B/…           27 here means DLE did not take
```

`tx_max_len = 27` would mean every notification is being fragmented across
link-layer packets whatever `BT_CTLR_DATA_LENGTH_MAX` says — worth knowing
before blaming the design.

## Safety notes

- **Never release a spike image.** The extra service lets anything in radio
  range make the node transmit continuously, which is both a battery and a
  privacy problem. It is a bench build, on the bench, with a console.
- The measurement holds the connection for its whole duration, and a connected
  node neither advertises nor samples (`ota_is_active()` gates the sensor loop
  in `main.c`), so the hub will see nothing from that hive while a run is going.
  That is expected, and it is also a useful preview of the off-air cost a real
  recording will have.
- `ota_release_arm_timeout()` exists only for this spike: `ota.c` otherwise drops
  any central that has not sent BEGIN within six seconds, which would cut every
  run short. It is compiled out of normal builds.

## Removing it

The question is answered, so this is now a live to-do rather than a
someday-note: delete `src/throughput.c/.h`,
`throughput-spike.conf`, `tools/throughput/`, this document, the
`ENABLE_THROUGHPUT_SPIKE` block in `src/hive_config.h`, the `src/throughput.c`
line in `CMakeLists.txt`, the `ota_release_arm_timeout()` pair in
`src/ota.c`/`src/ota.h`, and HiveHub's `tools/ble-throughput/`.

Nothing is compiled into a normal build in the meantime — the spike needs
`throughput-spike.conf` on the build command line — so leaving it in place is
harmless, just untidy.

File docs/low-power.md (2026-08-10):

# Reducing idle power on the XIAO nRF54LM20A Sense

This is a code-and-hardware audit for HiveInside's normal mode: continuous BLE
advertising with a sensor acquisition every five minutes. It deliberately
separates **idle current** from average current. A power analyzer is required
to validate the final number; component typical values are not a substitute
for a measurement of the assembled board.
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

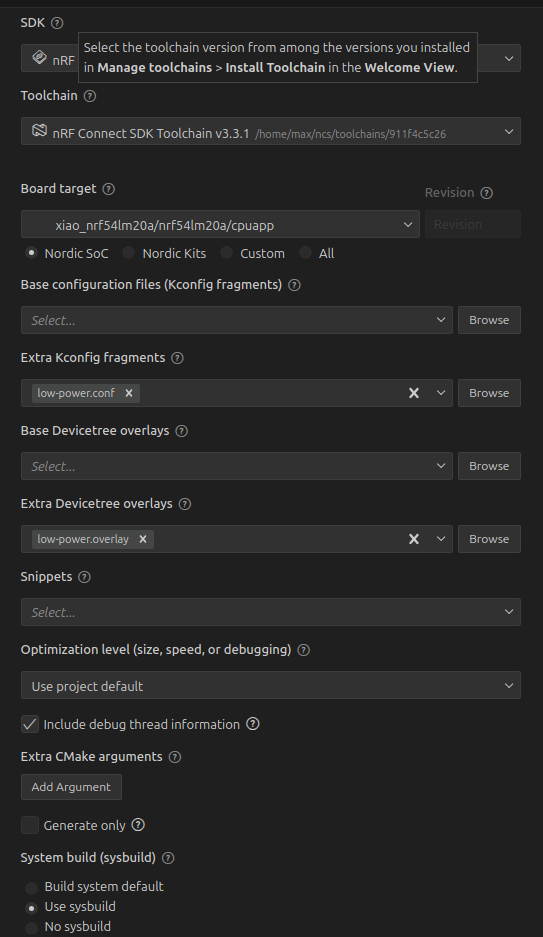
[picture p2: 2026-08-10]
docs/built config screenshot/lowpower.png

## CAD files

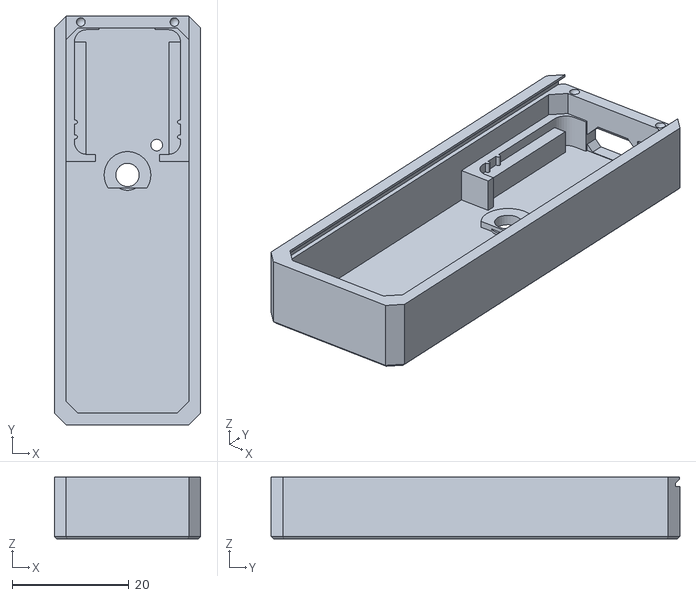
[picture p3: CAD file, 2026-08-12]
enclosure/Enclosure_Bottom.stl
25.0 x 70.0 x 10.6

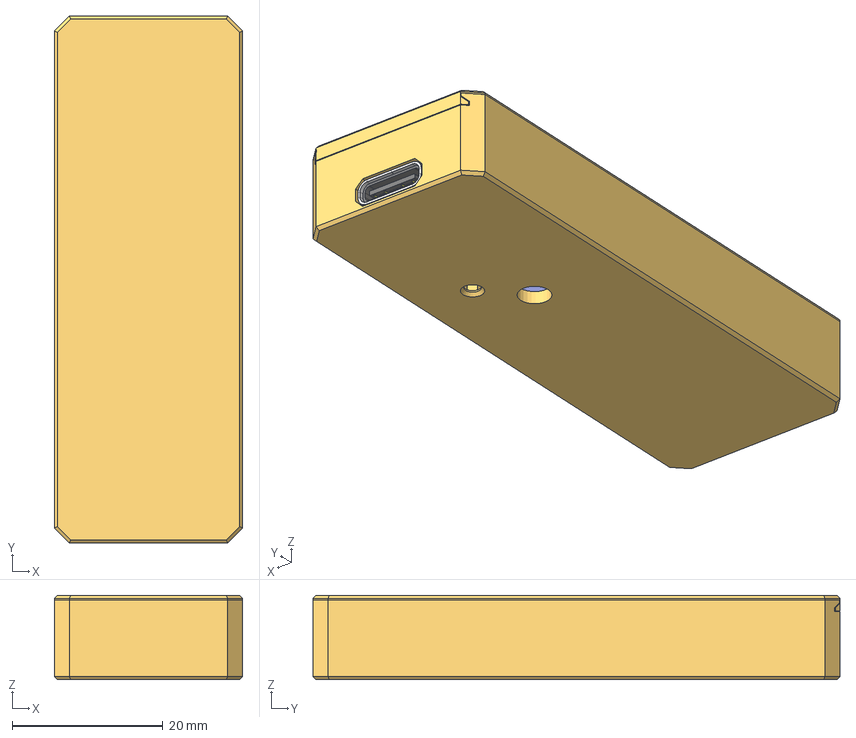
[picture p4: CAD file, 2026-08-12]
enclosure/HiveInside_Case.step
25.0 x 70.0 x 11.2 mm
XIAO nRF54l15_pad
XIAO nRF54l15_PCB
USB_type_C_smd_12ps v1
shield

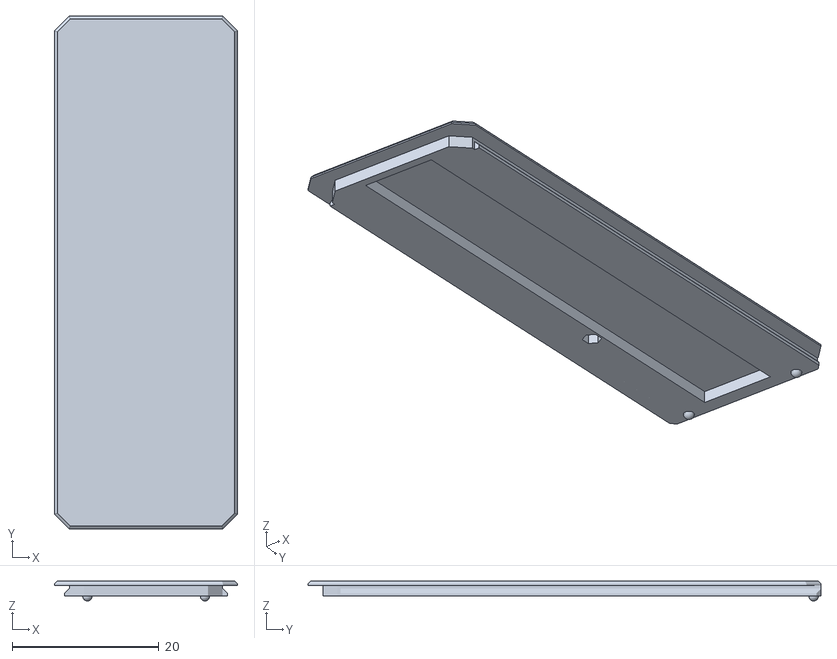
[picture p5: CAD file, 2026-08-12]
enclosure/Enclosure_Top.stl
25.0 x 70.0 x 2.73

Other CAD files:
enclosure/HiveInside_Case.f3z

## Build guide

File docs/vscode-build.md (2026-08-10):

# Building in VS Code / VSCodium (nRF Connect extension)

This is the complete build setup for HiveInside on the Seeed XIAO nRF54LM20A
Sense: two build configurations side by side — **`debug`**, the image with a
serial console, and **`lowpower`**, the deployment image built with the
[low-power profile](low-power.md). Both produce their own bootable
`merged.hex` and their own OTA payload, and you switch between them in the
sidebar. The build directory name *is* the configuration name the sidebar
shows, so the two names below are the only handle you have on them — keep them
as written.

For the command-line equivalent see [`flashing.md`](flashing.md); for what the
low-power profile actually changes and why, see [`low-power.md`](low-power.md).

## Prerequisites

* **nRF Connect for VS Code.** Published to the
  [Open VSX registry](https://open-vsx.org/extension/nordic-semiconductor/nrf-connect),
  so VSCodium can install it from its built-in marketplace. Nordic only tests
  Visual Studio Code and does not prioritise issues in other editors, but the
  extension does work in VSCodium.
* **An nRF Connect SDK install** (v3.3.1 is known to work here) and its matching
  toolchain, both selectable at the top of the build-configuration form.
* **The board definition.** `xiao_nrf54lm20a` is not in NCS's `sdk-zephyr`
  fork, so the NCS workspace needs it added out of tree — see the board-root
  section of [`flashing.md`](flashing.md). Once the board target appears in the
  dropdown, this is already sorted.

## Configuration 1 — `debug` (serial console)

**APPLICATIONS → `firmware-nrf54lm20a` → Add build configuration.**

| Field | Value |
|---|---|
| Board target | `xiao_nrf54lm20a/nrf54lm20a/cpuapp` |
| **Build directory name** | **`debug`** |
| Base configuration files (Kconfig fragments) | *(empty)* |
| Extra Kconfig fragments | *(empty)* |
| Base Devicetree overlays | *(empty)* |
| Extra Devicetree overlays | *(empty)* |
| Snippets | *(empty)* |
| Optimization level | Use project default |
| System build (sysbuild) | **Use sysbuild** |

Everything empty is correct. Zephyr picks up `prj.conf` and `app.overlay` on
its own, and the application's `CMakeLists.txt` selects the fixup overlay for
the active SDK (`ncs_fixups.overlay` here). This is the image to use for
anything you need to debug — hence the name: it is the only one that prints.

## Configuration 2 — `lowpower` (deployment)

**Add build configuration** a second time. Only three fields differ:

| Field | Value |
|---|---|
| Board target | `xiao_nrf54lm20a/nrf54lm20a/cpuapp` |
| **Build directory name** | **`lowpower`** |
| Base configuration files (Kconfig fragments) | *(empty)* |
| **Extra Kconfig fragments** | **`low-power.conf`** |
| Base Devicetree overlays | *(empty)* |
| **Extra Devicetree overlays** | **`low-power.overlay`** |
| Snippets | *(empty)* |
| System build (sysbuild) | **Use sysbuild** |

The build directory name is what keeps the two apart: each configuration owns
its own directory, so both images exist at once and the sidebar switches which
one **Build**, **Flash** and **Debug** act on.

### The one mistake this form invites

**Never put these files in a "Base" field.** The base fields are `CONF_FILE`
and `DTC_OVERLAY_FILE`, which *replace* `prj.conf` and `app.overlay`. The
"Extra" fields are `EXTRA_CONF_FILE` and `EXTRA_DTC_OVERLAY_FILE`, which merge
on top. The first field is labelled *"Base configuration files (Kconfig
fragments)"* — the parenthetical makes it read like the right choice, and it is
not.

Both mistakes are quiet in different ways:

* **`low-power.conf` in the base configuration field** replaces `prj.conf`, so
  the build has no Bluetooth, no MCUboot image manager and no sensor stack. This
  one at least fails loudly, while compiling `ota.c`:

  ```
  error: 'CONFIG_IMG_BLOCK_BUF_SIZE' undeclared here (not in a function)
  ```

* **`low-power.overlay` in the base devicetree field** replaces `app.overlay`,
  and **this one compiles cleanly and produces a broken image.** Lost with it:

  | Dropped from `app.overlay` | Consequence |
  |---|---|
  | `&pmic_i2c` pin correction (P1.18/P1.17) | nPM1300 unreachable; LDO1 stays at 1.8 V |
  | `&pmic` LDO1 at 3.3 V, `regulator-boot-on` | sensor rail under-volted |
  | `&pwm20` disabled, `&pdm20` enabled | PDM microphone never samples |
  | `&wdt31` enabled | no watchdog — a hang is permanent |

  In a deployment image there is no console to report any of it. The node boots,
  advertises, and reports `n/a` for sound.

## Verify before trusting a build

The extension prints the full `west build` command at the top of the build
output. Check all four:

1. The command line contains **`-DEXTRA_CONF_FILE`** and
   **`-DEXTRA_DTC_OVERLAY_FILE`** — no bare `-DCONF_FILE` or
   `-DDTC_OVERLAY_FILE`.
2. The application image merges **both** configurations, in this order:
   ```
   Merged configuration '.../prj.conf'
   Merged configuration '.../low-power.conf'
   ```
3. **All three** overlays are listed (the SDK-specific one is
   `ncs_fixups.overlay` in an nRF Connect SDK workspace):
   ```
   -- Found devicetree overlay: .../app.overlay
   -- Found devicetree overlay: .../ncs_fixups.overlay
   -- Found devicetree overlay: .../low-power.overlay
   ```
4. The `lowpower` image's `FLASH` figure is **visibly smaller** than the
   `debug` build's. The UART driver, console, `printk()` and the cbprintf
   floating-point formatter are all gone. Two near-identical sizes mean the
   fragment was not applied.

On the `debug` image, the console after flashing should show the watchdog
arming and the version you expect:

```
[HiveInside] nrf54lm20a fw 0.4.5 | USB + HiveHub BLE beacon
[WDT] armed: 60000 ms timeout, fed every 20000 ms
```

`[WDT] no enabled watchdog devicetree node` instead means `app.overlay` was
replaced — see the table above.

## Output artifacts

Each configuration writes to its own build directory:

```
debug/                              lowpower/
└── merged.hex                      └── merged.hex          ← SWD flashing
└── firmware-nrf54lm20a/zephyr/     └── firmware-nrf54lm20a/zephyr/
    ├── zephyr.signed.bin               ├── zephyr.signed.bin
    └── hiveinside-nrf54lm20a-          └── hiveinside-nrf54lm20a-
        v0.4.5-bringup.signed.bin           v0.4.5-lowpower.signed.bin
```

`merged.hex` is MCUboot plus the signed application and is what **Flash**
programs over SWD. The version-stamped `.signed.bin` is the OTA payload — upload
that rather than `zephyr.signed.bin`, because every configuration writes the
same `zephyr.signed.bin` filename and nothing distinguishes two of them once
they leave their build directories. See [`ota-over-ble.md`](ota-over-ble.md).

The `debug` configuration's payload is stamped **`-bringup`**, not `-debug`:
that suffix is derived from `CONFIG_SERIAL` in the image that was actually
built, so it describes the image rather than the configuration that requested
it, and it stays `-bringup` for any console-enabled build however it was
produced.

## Notes

* **Pristine builds.** After changing any field in the form, or after pulling
  changes that touch `prj.conf` or `app.overlay`, use **Pristine Build**. A warm
  build directory is exactly where Zephyr's caches mislead.
* **`Include debug thread information`** adds `-DCONFIG_DEBUG_THREAD_INFO=y` for
  debugger thread awareness. Harmless, and not part of the low-power profile —
  leave it on for `debug`, and off for `lowpower` if you want the smallest
  build.
* **Neither directory is `build/`.** `west` defaults to `build/`, so a
  command-line `west build`, `west flash` or `west debug` against a directory
  these configurations produced needs `-d debug` or `-d lowpower`. Without it
  `west` creates or reuses a third, unrelated build directory —
  [`flashing.md`](flashing.md) describes that plain command-line flow.
* **Browse vs typing.** The **Browse** button inserts absolute paths. Those work
  fine; plain relative filenames are resolved against the application directory
  and are easier to read.
* **Extra CMake arguments** stays empty. Passing
  `-DEXTRA_CONF_FILE=low-power.conf -DEXTRA_DTC_OVERLAY_FILE=low-power.overlay`
  by hand is exactly equivalent if you prefer it.
* **CI builds both configurations.** `.github/workflows/build.yml` runs the same
  `west --sysbuild` build for `debug` and `lowpower` against the Zephyr revision
  pinned in `west.yml`. It checks the MCUboot hex, signed application hex and
  payload with the expected variant suffix. Upstream Zephyr keeps the two flash
  domains separate; the nRF Connect SDK extension additionally presents their
  `merged.hex`. A green CI run means the fragments were actually applied — but
  it is not a substitute for flashing a deployment image before sealing a hive.

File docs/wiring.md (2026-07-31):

# HiveInside wiring reference

HiveInside uses a **Seeed XIAO nRF54LM20A Sense**, an external **SHT40**, and a
500 mAh LiPo battery. The XIAO Sense integrates the IMU, PDM microphone, power
management, charging, and USB-C; no external accelerometer or microphone is
needed for the primary target.

## SHT40

Connect the SHT40 to the XIAO's I²C bus:

| SHT40 pin | XIAO connection | Notes |
|---|---|---|
| VIN / VDD | 3V3 | Use the sensor's 3.3 V supply. |
| GND | GND | Common ground. |
| SDA | D4 (SDA) | I²C data. |
| SCL | D5 (SCL) | I²C clock. |

The SHT40's fixed I²C address is `0x44`. Use the current Seeed pinout and the
board devicetree when selecting any additional XIAO pins.

## Battery

Connect the 500 mAh single-cell LiPo to the XIAO battery connector, observing
its polarity. The XIAO's on-board nPM1300 PMIC manages charging over USB-C and
fuel-gauge functions.

## Optional: external accelerometer for bench work

The firmware identifies the accelerometer by `WHO_AM_I` on any enabled I²C bus,
so an external LIS3DH/LIS2DH12 breakout also works for bench comparisons.
Strap `SDO/SA0 → GND` for address `0x18` (or `→ VCC` for `0x19`) and wire SDA/SCL
to the same D4/D5 pads as the SHT40. It is not needed on the Sense module, whose
on-board LSM6DS3TR-C sits on the internal `i2c30` bus.

## Enclosure

The current 3D-printable enclosure release is kept in
[`enclosure/`](../enclosure/). It is sized for the XIAO nRF54LM20A Sense, SHT40,
and 500 mAh LiPo.

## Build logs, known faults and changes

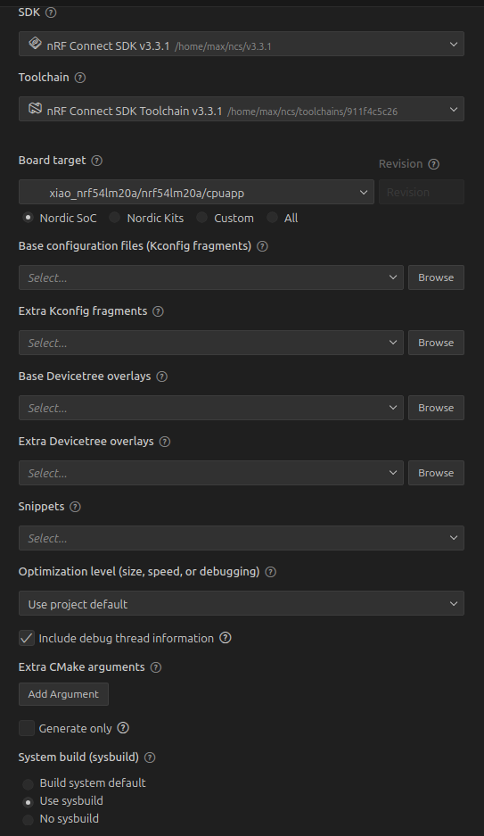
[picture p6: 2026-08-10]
docs/built config screenshot/debug.png

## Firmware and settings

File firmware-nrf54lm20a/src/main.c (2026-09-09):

/*
 * main.c — HiveInside XIAO nRF54LM20A Sense sensor readout (target 1).
 *
 * Bring up the sensor power rail, then every MEASURE_INTERVAL_MS read all four
 * sensors — SHT40 climate, LSM6DS3TR-C acceleration, PDM microphone level and
 * nPM1300 battery — and print the result to the USB serial console.
 *
 * "USB serial console": the on-board SAMD11 CMSIS-DAP debugger bridges the
 * SoC's uart20 to a USB CDC ACM port (/dev/ttyACM0) over the same USB-C cable
 * used for flashing, so printk() output appears on the host with no second
 * adapter. See docs/flashing.md. The console is a plain polled UART, so the
 * firmware boots and keeps sampling whether or not a terminal is attached.
 *
 * Alongside the plain readings it runs the same vibration and acoustic FFT band
 * analysis as HiveScale, prints those bands, and broadcasts the reduced
 * measurement in HiveHub's BLE manufacturer-data format.
 */
#include "accel.h"
#include "battery.h"
#include "beacon.h"
#include "hive_config.h"
#include "measurement.h"
#include "audio.h"
#include "link.h"
#include "mic.h"
#include "ota.h"
#include "power.h"
#include "sht40.h"
#include "watchdog.h"

#include <zephyr/kernel.h>
#include <zephyr/drivers/gpio.h>
#include <zephyr/sys/printk.h>
#include <zephyr/sys/reboot.h>
#include <zephyr/dfu/mcuboot.h>

#define MEASUREMENT_LED_NODE DT_ALIAS(led0)

#if DT_NODE_HAS_STATUS(MEASUREMENT_LED_NODE, okay)
static const struct gpio_dt_spec measurement_led =
	GPIO_DT_SPEC_GET(MEASUREMENT_LED_NODE, gpios);
static bool measurement_led_ready;

static void measurement_led_init(void)
{
	if (!gpio_is_ready_dt(&measurement_led)) {
		printk("[LED] built-in LED controller is not ready\n");
		return;
	}
	int err = gpio_pin_configure_dt(&measurement_led, GPIO_OUTPUT_INACTIVE);

	if (err != 0) {
		printk("[LED] built-in LED setup failed (%d)\n", err);
		return;
	}
	measurement_led_ready = true;
}

static void measurement_led_blink(void)
{
	if (!measurement_led_ready) {
		return;
	}
	(void)gpio_pin_set_dt(&measurement_led, 1);
	k_msleep(MEASUREMENT_LED_BLINK_MS);
	(void)gpio_pin_set_dt(&measurement_led, 0);
}
#else
static void measurement_led_init(void)
{
	printk("[LED] no led0 devicetree alias; measurement blink disabled\n");
}

static void measurement_led_blink(void)
{
}
#endif

/* Wait out the interval between sensor cycles in watchdog-sized slices.
 *
 * A single k_msleep(MEASURE_INTERVAL_MS) would force the watchdog timeout to
 * exceed the whole sampling period, which would let a driver hang go unnoticed
 * for five minutes. Sleeping in slices keeps the timeout sized against one
 * blocking call instead. The slice boundary is the only thing that changes:
 * the CPU is still idle for the entire interval apart from the feed itself. */
static void idle_between_cycles(void)
{
	uint32_t remaining = MEASURE_INTERVAL_MS;

	while (remaining > 0U) {
		uint32_t slice = MIN(remaining, (uint32_t)HIVE_WDT_FEED_INTERVAL_MS);

		k_msleep((int32_t)slice);
		remaining -= slice;
		hive_watchdog_feed();
	}
}

static void print_readout(const struct measurement *m)
{
	printk("---- HiveInside readout ----\n");

	if (m->sht_ok) {
		printk("  climate : %.2f C   %.1f %%RH\n", (double)m->temp_c,
		       (double)m->humidity_pct);
	} else {
		printk("  climate : n/a\n");
	}

	if (m->accel_ok) {
		printk("  accel   : x=%.1f y=%.1f z=%.1f mg  |a|=%.1f mg\n",
		       (double)m->accel_x_mg, (double)m->accel_y_mg,
		       (double)m->accel_z_mg, (double)m->accel_mag_mg);
		printk("  accel AC: rms=%.1f peak=%.1f mg  (%u@%uHz)\n",
		       (double)m->accel_rms_mg, (double)m->accel_peak_mg,
		       (unsigned)m->accel_sample_count,
		       (unsigned)m->accel_sample_rate_hz);
		printk("  vib FFT : swarm=%.2f fan=%.2f act=%.2f mg\n",
		       (double)m->accel_band_swarm_mg,
		       (double)m->accel_band_fanning_mg,
		       (double)m->accel_band_activity_mg);
	} else {
		printk("  accel   : n/a\n");
	}

	if (m->mic_ok) {
		printk("  sound   : rms=%.1f dBFS  peak=%.1f dBFS  (%u frames)\n",
		       (double)m->mic_rms_dbfs, (double)m->mic_peak_dbfs,
		       (unsigned)m->mic_frames);
		printk("  ac FFT  : sub=%.1f hum=%.1f pipe=%.1f stress=%.1f hi=%.1f dBFS\n",
		       (double)m->mic_band_sub_bass_dbfs,
		       (double)m->mic_band_hum_dbfs,
		       (double)m->mic_band_piping_dbfs,
		       (double)m->mic_band_stress_dbfs,
		       (double)m->mic_band_high_dbfs);
	} else {
		printk("  sound   : n/a\n");
	}

	if (m->battery_ok) {
		printk("  battery : %.3f V  ~%u%%\n", (double)m->battery_v,
		       (unsigned)m->battery_pct);
	} else {
		printk("  battery : n/a\n");
	}

	printk("----------------------------\n");
}

/* Rollback safety net for MCUboot test images. A healthy image confirms within
 * the first sensor cycle (seconds after boot); if confirmation has not happened
 * within this window the image is deemed unhealthy — radio never came up, the
 * main loop is wedged in a sensor driver, or the trailer write keeps failing —
 * and we reboot so MCUboot reverts to the previous image. The window is a
 * generous multiple of a normal first cycle yet well under MEASURE_INTERVAL_MS,
 * so recovery does not have to wait a full sampling period. */
#define OTA_CONFIRM_DEADLINE_MS 120000U

static void ota_confirm_deadline_expired(struct k_timer *timer)
{
	ARG_UNUSED(timer);
	/* Only ever armed while running an unconfirmed test image with a staged
	 * rollback target, so a reset here reverts to the previous known image. */
	printk("[OTA] health deadline expired without confirmation; rebooting for rollback\n");
	sys_reboot(SYS_REBOOT_COLD);
}

K_TIMER_DEFINE(ota_confirm_deadline, ota_confirm_deadline_expired, NULL);

int main(void)
{
	bool confirmation_pending;
	bool confirmation_attempted = false;
	int beacon_err;

	printk("\n[HiveInside] %s fw %s | USB + HiveHub BLE beacon\n",
	       HIVEINSIDE_BOARD, HIVEINSIDE_FW_VERSION);

	power_init();
	measurement_led_init();
	beacon_err = beacon_init();
	ota_init();
	audio_init();
	/* Armed after the one-time initialisation above, which is not covered by
	 * the watchdog: a hang in a driver's init would leave the node dark rather
	 * than reset-looping, and MCUboot's own rollback deadline below is the
	 * safety net for an image that cannot get this far. */
	hive_watchdog_init();
	/* power_init() owns the boot-time rail reference; normal users take their
	 * own references below. */
	(void)power_sensor_rail_disable();
	confirmation_pending = !boot_is_img_confirmed();
	/* Do not confirm a test image merely because main() was reached. Wait until
	 * one complete sensor cycle has run and Bluetooth has successfully published
	 * it; otherwise a regression in either path must remain eligible for MCUboot
	 * rollback on the next reset. */
	if (confirmation_pending && beacon_err != 0) {
		printk("[OTA] image left unconfirmed: Bluetooth init failed (%d)\n",
		       beacon_err);
	}
	/* Arm the rollback deadline only for a genuine test swap (a previous image
	 * is staged for revert). A directly SWD-flashed image reports swap type
	 * NONE and has no rollback target, so it is never armed and cannot boot
	 * loop; it still self-confirms through the normal path below. */
	if (confirmation_pending && mcuboot_swap_type() == BOOT_SWAP_TYPE_REVERT) {
		k_timer_start(&ota_confirm_deadline, K_MSEC(OTA_CONFIRM_DEADLINE_MS),
			      K_NO_WAIT);
	}

	while (true) {
		hive_watchdog_feed();

		if (link_is_busy()) {
			/* A firmware upload legitimately takes minutes. Polling here
			 * means the main thread is healthy, so keep feeding: the
			 * watchdog must not cut a transfer short. */
			k_msleep(100);
			continue;
		}
		if (!link_measurement_begin()) {
			continue;
		}
		struct measurement m = { 0 };

		/* LDO1 is normally off between cycles. Wake the IMU and microphone
		 * immediately before acquisition, then remove their standby load once
		 * both captures are complete. Climate and battery use other rails. */
		(void)power_sensor_rail_enable();
		sht40_read(&m);
		accel_read(&m);
		mic_read(&m);
		(void)power_sensor_rail_disable();
		link_measurement_end();
		battery_read(&m);

		print_readout(&m);
		if (beacon_publish(&m) == 0) {
			measurement_led_blink();
			if (confirmation_pending && !confirmation_attempted &&
			    !link_is_busy()) {
				/* Make at most one trailer-write attempt per boot. A persistent
				 * flash error must not cause periodic writes for the lifetime of
				 * the device; leaving the image unconfirmed preserves rollback. */
				confirmation_attempted = true;
				int confirm_err = boot_write_img_confirmed();

				if (confirm_err == 0) {
					confirmation_pending = false;
					k_timer_stop(&ota_confirm_deadline);
					printk("[OTA] test image confirmed after first complete cycle\n");
				} else {
					printk("[OTA] image confirmation failed (%d); no retry before reset\n",
					       confirm_err);
				}
			}
		}

		idle_between_cycles();
	}

	return 0;
}

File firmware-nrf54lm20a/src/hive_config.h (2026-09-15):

/*
 * hive_config.h — HiveInside XIAO nRF54LM20A Sense: identity, timing and
 * per-sensor settings.
 *
 * This firmware reads every sensor once per cycle and prints the result to the
 * USB serial console. Alongside the plain readings it runs the same vibration
 * and acoustic FFT band analysis as HiveScale, so a band value means the same
 * thing across the ecosystem. Each completed measurement is also broadcast in
 * the manufacturer-data format consumed by HiveHub.
 *
 * Hardware (see docs/wiring.md):
 *
 *   * Seeed XIAO nRF54LM20A Sense — nRF54LM20A (Cortex-M33 @ 128 MHz),
 *     on-board LSM6DS3TR-C 6-axis IMU, MSM261DGT006 PDM microphone and
 *     nPM1300 PMIC (LiPo charging + fuel gauge).
 *   * SHT40 — external temperature + humidity sensor on the XIAO I²C header.
 *
 * Every value can be overridden from the build (e.g. -DEXTRA_CFLAGS)
 * without editing this file. The firmware version is the
 * one deliberate exception — see the comment on it below.
 */
#pragma once

/* ── Identity ──────────────────────────────────────────────────────────── */

/* Firmware version — single source of truth.
 *
 * These three numbers are the version that actually leaves the device: beacon.c
 * puts them in the scan-response identity record, and that record is the only
 * way a relay or the backend can tell which firmware a node is running. The
 * console banner string and the release artifact name (see ../CMakeLists.txt)
 * are both derived from them.
 *
 * They used to be maintained alongside a separate "0.4.2" string literal.
 * Bumping only the string produced firmware that installed correctly over the
 * air and then went on advertising the old version — from the backend that is
 * indistinguishable from an OTA that silently did nothing, because there is no
 * error anywhere to report. Deriving the string removes that failure mode.
 *
 * This is the one setting in this file deliberately *not* overridable from the
 * build: a release version is a committed fact, and a -D override would let the
 * stamped artifact name disagree with the bytes on the air. Bump it here.
 */
#define HIVEINSIDE_FW_VERSION_MAJOR 0
#define HIVEINSIDE_FW_VERSION_MINOR 6
#define HIVEINSIDE_FW_VERSION_PATCH 3

#define HIVEINSIDE_STRINGIFY_(value) #value
#define HIVEINSIDE_STRINGIFY(value) HIVEINSIDE_STRINGIFY_(value)
#define HIVEINSIDE_FW_VERSION                                 \
	HIVEINSIDE_STRINGIFY(HIVEINSIDE_FW_VERSION_MAJOR) "." \
	HIVEINSIDE_STRINGIFY(HIVEINSIDE_FW_VERSION_MINOR) "." \
	HIVEINSIDE_STRINGIFY(HIVEINSIDE_FW_VERSION_PATCH)
#ifndef HIVEINSIDE_BOARD
#define HIVEINSIDE_BOARD "nrf54lm20a"
#endif
/* Stable wire identifier for the Seeed XIAO nRF54LM20A board. */
#define HIVEINSIDE_BOARD_ID 2U

/* Human-readable identity shown by active BLE scanners during setup. The
 * manufacturer name is also kept here as explicit product metadata; BLE
 * manufacturer-data packets carry a numeric company ID, not a name string.
 *
 * This is only the *prefix*: beacon_init() appends a hyphen and the last two
 * bytes of the node's identity address, so what actually goes on the air is
 * "HiveInside-8A3F". Every node advertising the same bare "HiveInside" made a
 * yard with more than one of them unreadable — a scanner listed several
 * identical entries, and the only thing telling them apart was the raw address
 * a beekeeper has no reason to have memorized. The suffix is derived from the
 * address rather than stored, so it needs no provisioning step and survives a
 * factory erase.
 */
#ifndef HIVEINSIDE_DEVICE_NAME
#define HIVEINSIDE_DEVICE_NAME "HiveInside"
#endif

/* "-" plus four hex digits, appended to HIVEINSIDE_DEVICE_NAME. */
#define HIVEINSIDE_DEVICE_NAME_SUFFIX_LEN 5U
#define HIVEINSIDE_DEVICE_NAME_MAX \
	(sizeof(HIVEINSIDE_DEVICE_NAME) - 1U + HIVEINSIDE_DEVICE_NAME_SUFFIX_LEN)
#ifndef HIVEINSIDE_MANUFACTURER_NAME
#define HIVEINSIDE_MANUFACTURER_NAME "HiveInside"
#endif

/* Manufacturer/company ID at bytes 0..1 of the manufacturer-specific data.
 * 0x02E5 is retained for wire compatibility with the existing HiveHub decoder;
 * the following 'H' magic and format version identify this as HiveInside. */
#ifndef HIVEINSIDE_COMPANY_ID
#define HIVEINSIDE_COMPANY_ID 0x02E5
#endif

/* A one-second connectable advertising interval is short enough to be
 * heard reliably in HiveHub's scan window while allowing the controller to
 * sleep between three brief advertising-channel transmissions. BLE intervals
 * use 0.625 ms units. */
#ifndef BLE_ADV_INTERVAL_MS
#define BLE_ADV_INTERVAL_MS 1000
#endif
#define BLE_ADV_INTERVAL_UNITS ((BLE_ADV_INTERVAL_MS * 8U) / 5U)

/* ── Measurement cadence ───────────────────────────────────────────────── */
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

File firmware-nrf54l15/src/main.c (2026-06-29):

/*
 * HiveInside — XIAO nRF54L15 Sense bring-up: Step 1, blinky.
 *
 * Goal of this step: prove the toolchain, the board target and the flashing
 * path all work end-to-end before any sensors or BLE are involved. If the
 * on-board user LED blinks, your nRF Connect SDK setup is good.
 *
 * Board target: xiao_nrf54l15/nrf54l15/cpuapp
 *
 * We drive the LED through the `led0` devicetree alias that the Seeed board
 * files provide. The LED's active-low wiring (XIAO user LEDs are active-low)
 * is encoded as a GPIO_ACTIVE_LOW flag in the board's devicetree, so we toggle
 * *logically* and let Zephyr translate to the right electrical level. That is
 * why this file has no board-specific pin numbers — it is portable by design.
 */
#include <zephyr/kernel.h>
#include <zephyr/drivers/gpio.h>

#define BLINK_PERIOD_MS 500

/* Resolved at build time from devicetree: DT_ALIAS(led0) -> the board's LED. */
static const struct gpio_dt_spec led = GPIO_DT_SPEC_GET(DT_ALIAS(led0), gpios);

int main(void)
{
	if (!gpio_is_ready_dt(&led)) {
		printk("LED gpio device not ready\n");
		return 0;
	}

	if (gpio_pin_configure_dt(&led, GPIO_OUTPUT_ACTIVE) < 0) {
		printk("Failed to configure LED gpio\n");
		return 0;
	}

	printk("HiveInside nRF54L15 blinky up — toggling led0 every %d ms\n",
	       BLINK_PERIOD_MS);

	while (1) {
		gpio_pin_toggle_dt(&led);
		k_msleep(BLINK_PERIOD_MS);
	}

	return 0;
}

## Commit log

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2026-06-16 fix(esp32c6): stop BLE advertising overflow + harden I2C bring-up
    Three issues surfaced on the first prototype bring-up:
    * NimBLE "Data length exceeded": the primary advertising packet was
    flags(3) + BTHome service-data(18) + name(12) = 33 B, over the 31-byte
    legacy advertising limit. Drop the redundant BTHome voltage object
    (battery % is still advertised; raw voltage stays in the scan-response
    blob and the GATT JSON), bringing the packet to 30 B.
    * I2C ESP_ERR_INVALID_STATE (259): default the bus to 100 kHz (new
    I2C_CLOCK_HZ, overridable) so marginal breadboard pull-ups work, and
    add a startup I2C scan so an unwired/unpowered sensor is obvious rather
    than looking like a firm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
2026-06-16 fix(esp32c6): route Serial to USB CDC and advertise continuously
    Two reasons the prototype showed nothing over USB and couldn't be found
    by scanners:
    * Serial over USB: the SuperMini's USB-C is the C6's native USB
    Serial/JTAG, but ARDUINO_USB_CDC_ON_BOOT was not set, so Arduino's
    Serial.* went to UART0 (TX/RX pins) and never reached USB — only the
    low-level IDF console did. Enable ARDUINO_USB_MODE / CDC_ON_BOOT.
    * Discoverability: advertising mode started the radio, delayed
    ADV_BURST_MS (3 s), then stopped — and the next publish is
    MEASURE_INTERVAL_MS (5 min) later, leaving the device invisible ~99%
    of the time. Advertise continuously and just refresh the payload each
    cyc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
2026-06-17 feat: firmware-over-BLE (OTA) target support
    Add an OTA receiver to the connectable GATT server so HiveScale can stream a new
    image into this device over BLE. The image is written straight to the inactive
    OTA slot via the Arduino Update API and only committed after an end-to-end
    CRC-32 (zlib-compatible, reflected poly 0xEDB88320) verifies it — a dropped or
    corrupted transfer always leaves the device on its current image.
    - ble_link.cpp/.h: OTA control/data/status characteristics in the custom
    HiveInside service, a BEGIN/DATA/END/ABORT state machine, isOtaActive() and
    loopOta() (deferred reboot into the new slot).
    - main.cpp: pump loopOta() and suppress measurement/deep-sleep during a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
    [partitions_4mb_ota_no_fs.csv]
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2026-06-22 Harden BLE wake-rendezvous against deep-sleep timer drift
    Widen and re-balance the synced-wake window so the in-hive sensor stays
    aligned with HiveScale despite RC-oscillator drift between the two
    free-running deep-sleep timers (the internal ~150kHz RC clock slips several
    percent with temperature, so a 10-min interval can drift tens of seconds
    per cycle).
    - SYNC_LISTEN_MS 45s -> 150s. This window is only fully consumed on a MISSED
    rendezvous (a healthy cycle sleeps the instant HiveScale disconnects), so
    it costs extra awake time only on the cycles it actually rescues.
    - On a missed rendezvous, fall back to the last cadence HiveScale gave us
    (retained in RTC memory across deep sleep) i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
2026-06-22 docs: condense docs and retarget to XIAO ESP32-C6 / XIAO nRF52840
    Make the documentation consistent and current, and set the correct board
    plan: XIAO ESP32-C6 for current prototyping and XIAO nRF52840 (or its SMD
    module) for the final board, with affiliate links.
    - Resolve the contradiction where firmware targets an ESP32-C6 but README,
    flashing and wiring described an nRF52840 Nice!Nano / Ebyte E73 design with
    build envs (nice_nano, e73_custom) and a firmware-esp32c6/ path that do not
    exist. Docs now match the real firmware.
    - Firmware: rename the board identity to the XIAO ESP32-C6 and fix the pin map
    to the XIAO header pads (I2C D4/D5=GPIO22/23, I2S D6-D8=GPIO16/17/19,
    LED=GPIO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
    [bom.csv]
2026-06-23 Replace INMP441 I2S microphone with MP34DT01/MP34DT06 PDM mic
    Swap the acoustic front-end from the INMP441 (I2S, 24-bit) to a PDM MEMS
    microphone: MP34DT01 for the prototype, MP34DT06 for the final SMD board.
    The ESP32-C6's I2S peripheral has a hardware PDM receiver, so the mic needs
    only two signal pins (clock out + data in) instead of three.
    Firmware (firmware/):
    - mic.cpp: capture via driver/i2s_pdm.h (i2s_channel_init_pdm_rx_mode) instead
    of i2s_std.h. PDM RX delivers 16-bit PCM, so FULL_SCALE becomes 2^15 (was
    2^23) and the per-sample >>8 shift is removed. The Hann-window FFT and the
    five dBFS bands (50-3000 Hz) at 16 kHz are unchanged, so band semantics stay
    aligned with HiveS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
    [bom.csv]
2026-06-24 docs: sync C6 prototype mic section with the raw-PDM firmware
    The prototype doc still described the pre-rework microphone design: it listed
    the PDM pins as D2/D3 (GPIO2/21) and the clock as MIC_SAMPLE_RATE x 64 =
    1.024 MHz via a hardware decimator. The firmware now uses D6/D8 (GPIO16/19)
    and captures raw PDM at MIC_SAMPLE_RATE x MIC_PDM_DECIMATION = 2.048 MHz,
    decimating 128:1 to 16 kHz PCM in software (the ESP32-C6 has no hardware
    PDM-to-PCM converter).
    - Pin table: PDM CLK -> D6/GPIO16, PDM DATA -> D8/GPIO19 (matches config.h).
    - Note that D6/D7 are the UART pins, free because Serial is on native USB.
    - Rewrite the "PDM clock & levels" note to describe the software sinc^3 (CIC)
    decimato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
2026-06-24 firmware: make PDM RX MCLK multiple a tunable knob
    Expose MIC_PDM_MCLK_MULTIPLE (default I2S_MCLK_MULTIPLE_256, the IDF default)
    and apply it to the PDM RX clk config in mic::begin(). For raw PDM the IDF
    derives the 2.048 MHz line clock from sample_rate_hz via bclk_div rather than
    from MCLK = sample_rate * mclk_multiple, so x256 is correct and behavior is
    unchanged; this just gives a single documented override to lower first if
    i2s_channel_init_pdm_rx_mode() ever reports a clock error on a given core/board.
    Claude-Session: https://claude.ai/code/session_01BscojhWEeChqG9RWGesPAD
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2026-07-02 Migrate nRF54 firmware target from XIAO nRF54L15 to XIAO nRF54LM20A
    Replace all references to the Seeed XIAO nRF54L15 Sense with the newer
    XIAO nRF54LM20A Sense across the nRF54 firmware:
    - Rename firmware-nrf54l15/ -> firmware-nrf54lm20a/
    - Update Zephyr board target xiao_nrf54l15/nrf54l15/cpuapp ->
    xiao_nrf54lm20a/nrf54lm20a/cpuapp in CMakeLists, README, and main.c
    - Update chip-intrinsic specs (2 MB RRAM, 512 KB RAM), project name,
    and all documentation/comment references
    Pin mapping is unaffected: the blinky uses the led0 devicetree alias
    from the Seeed board files, so it carries no hardcoded pin numbers.
    Claude-Session: http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
    [main.c]
2026-07-06 docs+hardware: retarget final board from XIAO nRF52840 to XIAO nRF54LM20A Sense
    Replace every nRF52840 reference with the Seeed XIAO nRF54LM20A Sense
    (with the nRF54L15 Sense as a documented drop-in alternative) across the
    README, docs, KiCad notes, BOM and ESP32-C6 prototype comments.
    Because the nRF54LM20A/L15 Sense integrates the 6-axis IMU (LSM6DS3TR-C)
    and PDM mic (MSM261DGT006) on-module and uses an nPM1300 PMIC plus an
    on-board CMSIS-DAP debugger, the swap also corrects the technical claims
    that were nRF52840-specific:
    - final board sensor list: IMU + mic are now on-board, not external SMD
    - wiring: drop the nRF52840 pin table, mic power-gating MOSFET and PDM
    guard parts; defer pad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
    [bom.csv]
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2026-07-21 Fix LED polarity comment and stale nRF54L15 doc references
    - main.c claimed the user LED is active-low with GPIO_ACTIVE_LOW in the
    devicetree; the Seeed xiao_nrf54lm20a board files wire all three user
    LEDs GPIO_ACTIVE_HIGH. Behavior was unaffected (the blinky only
    toggles), but the comment would mislead non-toggle LED code.
    - hardware/kicad/README.md and docs/wiring.md still offered the XIAO
    nRF54L15 Sense as an equal alternative; clarify that it only fits the
    carrier hardware, while this repo's firmware targets the nRF54LM20A.
    Claude-Session: https://claude.ai/code/session_01NnNyUai3duicC3CyaYvVzy
    [main.c]
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2026-07-21 Port ESP32-C6 firmware to nRF54LM20A: BLE beacon + OTA-over-GATT placeholder
    Replace the nRF54LM20A blinky bring-up with the full HiveInside sensor
    application, ported from the deprecated ESP32-C6 prototype to Zephyr.
    Sensors (all degrade to "absent" in the beacon flags when missing):
    - SHT40 temperature/humidity over raw I2C (external, XIAO header bus)
    - On-board LSM6DS3TR-C IMU vibration RMS/peak + swarm/fanning/activity FFT
    bands (auto-detects a prototype-style external LIS3DH too)
    - On-board MSM261DGT006 PDM microphone acoustic RMS/peak + five FFT bands,
    via the Zephyr dmic API (the nRF PDM peripheral filters to PCM in hardware,
    so the prototype's software CIC decimator is dropped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
    [accel.c]
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2026-07-21 fix(nrf54): correct LDO1 DT_CHILD casing so power_init runs
    The PMIC sensor-rail fix changed power.c's DT_CHILD() child argument from
    `ldo1` to `LDO1` to match the DTS node name. But DT_CHILD() requires the
    lowercase-and-underscores form of the node name: Zephyr lowercases node
    names when generating devicetree identifiers (str2ident -> s.lower()), so
    the DTS node `LDO1` yields the token `..._S_ldo1`. Passing `LDO1` made
    DT_NODE_EXISTS() false, which silently selected the no-op power_init()
    stub — leaving the IMU/mic rail unmanaged (only enabled via boot-on, never
    programmed to 3.3 V).
    Revert the C-side spelling to `ldo1` (the DTS overlay keeps `LDO1`, which is
    correct at the devicetree le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
2026-07-22 fix(nrf54): default to pyOCD upload so external CMSIS-DAP probes work
    The Seeed board definition's cmsis-dap/OpenOCD upload path is invoked with
    a fixed Seeed CMSIS-DAP VID:PID filter (0x2886:0x0068). A generic external
    SWD probe -- e.g. a XIAO RP2040 running Raspberry Pi Debugprobe, which
    enumerates as 0x2E8A:0x000C -- is filtered out, so `pio run -t upload`
    fails with "unable to find a matching CMSIS-DAP device".
    Set upload_protocol = pyocd in platformio.ini; pyOCD auto-detects any
    connected CMSIS-DAP probe and applies no VID:PID filter. probe-rs is the
    documented fallback if pyOCD lacks the nRF54LM20A target pack.
    Document the XIAO-RP2040-as-probe workflow (Debugprobe firmware, SWD
    wiri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
2026-07-23 fix(nrf54): make printk/log reach the USB serial console
    The XIAO nRF54LM20A Sense has an on-board SAMD11 CMSIS-DAP debugger that
    owns the USB-C port; besides SWD flashing it bridges the SoC's uart20
    (P1.11/P1.10, internal pins — not the XIAO header) to a USB CDC ACM port
    (/dev/ttyACM0). The board definition already chooses uart20 as the
    console, so the transport was correct. The console looked silent because
    the firmware prints everything with printk(), and CONFIG_LOG=y makes
    Zephyr default CONFIG_LOG_PRINTK=y, rerouting every printk() into the
    deferred logging pipeline instead of the UART console.
    Config (both prj.conf copies kept identical):
    - CONFIG_LOG_PRINTK=n so printk() writes str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
2026-07-23 fix(nrf54): drop CONFIG_LOG_MODE_IMMEDIATE to de-risk early-boot faults
    Field testing showed the board re-enumerating its on-board SAMD11 CMSIS-DAP
    debugger in a loop while the firmware runs (USB device number climbing),
    stable only when the SoC is held in reset — i.e. the running firmware is
    resetting in a loop, matching the earlier OpenOCD "double fault -> lockup
    -> HardFault @ 0xEFFFFFFE".
    Of this branch's changes, only CONFIG_LOG_MODE_IMMEDIATE=y has any runtime
    effect: it renders logs synchronously in the caller's context, including
    during Bluetooth bring-up, which can fault from a constrained context. The
    application logs exclusively via printk (routed direct to the console by
    CONFI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
2026-07-24 fix(nrf54): select software LL controller to match the chosen HCI node
    bt_enable() faulted at boot with an MPU fault (Data Access Violation,
    MMFAR 0x9). addr2line on the faulting PC resolved it to
    net_buf_alloc_len -> pool_get_uninit (lib/net_buf/buf.c): a NULL __bufs
    in a Bluetooth net_buf pool, hit on the first buffer allocation during
    controller/HCI bring-up.
    Root cause: app.overlay selects the Zephyr software link-layer controller
    node (`zephyr,bt-hci = &bt_hci_controller`), but prj.conf never set
    CONFIG_BT_LL_SW_SPLIT=y. The pinned Seeed board defaults the Kconfig
    controller choice to the Nordic SoftDevice Controller (bt_hci_sdc), so the
    build wired up the SoftDevice controller while t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
2026-07-25 firmware-nrf54lm20a: add vibration + acoustic FFT band analysis
    Layer the same FFT band analysis the ESP32-C6 prototype produces on top of
    the plain sensor readout, and print those bands to the console alongside the
    raw readings. Bands, units, windowing and normalisation match the prototype
    so a value means the same thing across the ecosystem.
    * Restore the dependency-free radix-2 fft.c/fft.h (Hann window, magnitude,
    root-sum-square band amplitude with FFT+Hann gain undone).
    * accel.c now captures ~1024 samples of |a| at ~400 Hz and reduces them to
    the swarm (8-30 Hz), fanning (30-100 Hz) and activity (100-200 Hz) bands in
    mg, plus broadband AC rms/peak. It still reports the mean X/Y/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
    [accel.c, hive_config.h, main.c]
2026-07-25 firmware-nrf54lm20a: fix nPM1300 I2C pins so the mic gets 3.3V
    The microphone read returned no PCM data ("[MIC] read stopped after 0
    frames" / "no PCM samples") because the on-board nPM1300 PMIC was never
    reachable, so LDO1 could not be raised from its 1.8 V board default to the
    3.3 V the MSM261DGT006 microphone requires.
    Root cause: the board devicetree routes the PMIC's bit-banged I2C to
    P1.15 (SDA) / P1.16 (SCL), but the actual XIAO nRF54LM20A Sense hardware
    wires the nPM1300 to P1.18 (SDA) / P1.17 (SCL) — a documented board-DTS vs
    hardware mismatch (see Seeed's on-board-sensor reference). The old overlay
    even asserted the opposite and deliberately did not override the routing.
    Overri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
2026-07-25 firmware-nrf54lm20a: disable pwm20 so the PDM mic can sample
    The nPM1300 I2C pin fix alone did not restore the microphone: dmic_read
    still timed out with zero DMA blocks. On the nRF54L the "20" peripheral group
    multiplexes pdm20 and pwm20 onto the same block/pins, and the board enables
    pwm20 by default — so pdm20 could be configured and started but never actually
    sampled.
    Disable pwm20 in the overlay to release the slot to the microphone, matching
    Seeed's working on-board-mic reference overlay. Applied to both overlay copies
    (config-sync).
    Claude-Session: https://claude.ai/code/session_01En4fJrCMMKMm2wXkhU5E4p
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2026-07-25 firmware-nrf54lm20a: keep beacon booting when scannable adv is rejected
    PR #41 switched the beacon from a non-connectable advert (ADV_NONCONN_IND)
    to a scannable one (ADV_SCAN_IND) so an active setup scan can read the
    "HiveInside" name from a scan response. main.c ignores the beacon return
    value, so if bt_le_adv_start() rejects that combination the node is left
    without a working advert (no HiveHub data, appearing stuck).
    Make the publish path self-heal: if the scannable start is rejected, log
    the error and fall back to the known-good non-connectable advert so the
    measurement keeps reaching HiveHub; the friendly name becomes best-effort.
    Subsequent bt_le_adv_update_data() calls follow whiche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
2026-07-25 Revert "firmware-nrf54lm20a: advertise board + firmware identity record"
    This reverts commit 286183e42b79bc2529e97c6fef407d2196babf59.
    [hive_config.h]
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2026-07-26 firmware-nrf54lm20a: fix silent-boot trap from MCUboot + PlatformIO flow
    PR #48 turns on MCUboot (CONFIG_BOOTLOADER_MCUBOOT=y) so the firmware can
    accept BLE OTA, but the build/flash flow was never migrated to match. The
    Seeed PlatformIO Zephyr builder builds a single application image and has no
    sysbuild support, so it never builds MCUboot, signs the app, or emits a merged
    hex; sysbuild.conf/sysbuild/mcuboot.conf are ignored by `pio run`.
    With MCUboot enabled the application is linked at the slot-0 offset behind an
    image header. `pio run` still compiles (the "build test passes"), but
    `pio run -t upload` flashes that application-only image with nothing at 0x0, so
    the CPU faults before main(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
2026-07-26 firmware-nrf54lm20a: disable unused nRF54 USBHS wrapper for NCS builds
    Building with nRF Connect SDK (west --sysbuild) fails to compile
    zephyr/drivers/usb/common/nordic/nrf_usbhs_wrapper.c with
    "__device_dts_ord_N undeclared" from a DEVICE_DT_GET() on a USB regulator
    device that this non-USB configuration never instantiates.
    CONFIG_NRF_USBHS_WRAPPER is `default y` and only depends on the USBHS wrapper
    devicetree node being enabled and CONFIG_REGULATOR=y. The nPM1300 fuel gauge
    and LDO control require CONFIG_REGULATOR, and NCS's board definition leaves the
    USBHS node enabled, so the wrapper driver builds itself in and then references
    a regulator device that is not present.
    This firmware doe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
2026-07-27 firmware-nrf54lm20a: reboot unconfirmed OTA test image after a deadline
    An MCUboot test image that boots but never becomes healthy (radio never
    comes up, the main loop wedges in a sensor driver, or the trailer write
    keeps failing) previously ran unconfirmed indefinitely. MCUboot only
    reverts on the next reset and nothing forced one, so a bad OTA could sit
    active for up to a full MEASURE_INTERVAL_MS (5 min) or longer.
    Arm a 120 s confirmation deadline at boot. A healthy image confirms within
    the first sensor cycle and stops the timer; otherwise the timer reboots so
    MCUboot reverts to the previous image. The deadline is armed only when
    MCUboot reports a real test swap (BOOT_SWAP_TYPE_REVERT),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
    [main.c]
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2026-07-31 docs: sync documentation with the nRF54-only codebase
    The ESP32-C6 prototype firmware was deleted in 0a71931, but no
    documentation was updated with it. Every doc still linked to the
    removed firmware-esp32-c6/ tree, and several described behaviour the
    current firmware no longer has.
    ESP32-C6 removal:
    - delete docs/esp32c6-prototype.md (documented deleted code)
    - drop the prototype sections/links from README, flashing, wiring and
    ota-over-ble; all relative links now resolve
    - reword source comments that used the prototype as the reference for
    the shared FFT bands to name HiveScale/HiveHub instead (comments only,
    no code change)
    Stale claims corrected:
    - README said OTA was unimplemente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
    [accel.c, hive_config.h, main.c]
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2026-08-04 feat(nrf54lm20a): add a hardware watchdog and pin tickless idle
    A sealed in-hive node has no console and nobody watching it, so a hang inside a
    sensor driver — a stuck I2C transfer, a dmic_read() that never returns — left
    the firmware alive enough to keep advertising the last good measurement
    indefinitely. From HiveHub that is indistinguishable from a hive that stopped
    changing. There was no watchdog anywhere in the tree.
    - New src/watchdog.[ch]: install a 60 s WDT_FLAG_RESET_SOC timeout and start
    the watchdog. The node is resolved by watchdog0 alias first, then by
    nordic,nrf-wdt compatible, following mic.c's precedent; with no enabled node
    the module compiles to stubs and the bui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
    [hive_config.h, main.c]
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2026-08-04 fix(nrf54lm20a): make the advertised firmware version a single source of truth
    The version existed twice in hive_config.h: HIVEINSIDE_FW_VERSION as a "0.4.2"
    string literal used only for the console banner, and a separate hardcoded
    MAJOR/MINOR/PATCH triple. The triple is what actually leaves the device —
    beacon.c puts it in the scan-response identity record, which is the only way a
    relay or the backend can see which firmware a node runs.
    Bumping only the string therefore produced firmware that installed correctly
    over the air and then went on advertising the old version. There is no error
    anywhere in that path, so from the backend it is indistinguishable from an OTA
    that silently did noth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
    [hive_config.h]
2026-08-04 fix(nrf54lm20a): abandon an OTA transfer that stalls mid-stream
    A transfer in progress had no timeout at all. The six-second arm timeout is
    cancelled the moment BEGIN arrives, so once state reached OTA_RECEIVING nothing
    bounded the session: a relay that opened a session and then went quiet while
    holding the BLE link left the node in OTA_RECEIVING indefinitely.
    That takes the node off the air completely. ota_is_active() gates the sensor
    loop, so no measurements are taken, and because the node is connected it is not
    advertising either — HiveHub sees nothing, which reads as a relay stuck
    "in progress" for as long as the link is held. The watchdog cannot help: the OTA
    path feeds it deliberate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
    [hive_config.h]
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2026-08-05 firmware: bump version to 0.4.4
    The MAJOR/MINOR/PATCH triple in hive_config.h is the single source of truth —
    beacon.c advertises those bytes in the scan-response identity record, the
    banner string is derived from them, and CMakeLists.txt reads them to name the
    signed OTA payload. Bumping the triple is the whole change.
    Also refreshes the sample banner output and artifact names in the docs, which
    had drifted to two different versions between 0.4.2 and 0.4.3. The one
    remaining 0.4.2 in hive_config.h is deliberate: it is the historical note about
    the duplicated string literal this scheme replaced.
    Claude-Session: https://claude.ai/code/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
    [hive_config.h]
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2026-08-10 Instrument OTA flash failures for hardware diagnosis
    This is a diagnostic build, not a speculative flash fix. It reports the slot geometry and exact flash_img errno so the first hardware run can identify the real cause.
    [hive_config.h]
2026-08-11 fix(nrf54lm20a): give RRAM writes a usable radio timeslot so OTA can flash
    Every OTA failed at exactly 488 bytes with OTA_ERR_WRITE (state 0x12). The
    number is the whole diagnosis: 488 = 2 x 244, so BEGIN and the first two DATA
    chunks succeed and the third fails — that third write is the one that first
    fills stream_flash's 512-byte buffer and therefore triggers the first real
    flash_write() of the transfer. Nothing before it touched flash at all.
    Writing RRAM with the controller running is a scheduled operation, not a plain
    memory write. Upstream Zephyr's link layer makes SOC_FLASH_NRF_RADIO_SYNC_TICKER
    the RRAM driver's default, so each flash_write() runs inside a ticker-scheduled
    radio t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
    [hive_config.h]
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2026-09-07 Add a temporary BLE notification-throughput spike (#71 phase 0e)
    Issue #71 asks for an on-request audio recording, which means moving a clip
    from the node to the relay as GATT notifications out of RAM. Nothing in this
    firmware does that, so nothing measures it. The only figure available is the
    OTA relay's, measured on a deployment at ~1-1.5 kB/s -- and that path is a poor
    proxy in three ways that all push the same direction: it is central to
    peripheral, every chunk is a write WITH RESPONSE (two connection intervals
    minimum), and data_write() flushes RRAM synchronously inside the ATT callback,
    where each 512-byte write runs in a radio timeslot that pre-empts connection
    events. It largely meas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
    [hive_config.h]
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2026-09-14 Fix sensor fault handling and secure OTA releases
    [accel.c, hive_config.h]
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
